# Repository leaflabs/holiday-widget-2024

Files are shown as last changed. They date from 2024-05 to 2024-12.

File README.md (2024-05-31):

# Holiday Widget

Basic startup project for NUCLEO-L053R8 board. 

Source code lives in firmware.

The build directory holds all .o files for compliation. The output binary is build/blink.elf. This folder is generated at compilation time and will not exist upon cloning the repository.

Include holds all user created .h files. For the HAL to work, the stm3l0xx_hal_conf_template.h file needs to be copied and adjusted as necessary. No changes were made as of now. 

src holds all user created .c files. This project does not use the c library so some builtin functions needed to be defined, namely __libc_init_array, memset and memcpy. main.c holds the main function and the basic code to blink the LD2 LED at a different speed when the B1 button is pressed.

linker_script.ld defines how the binary should be setup.  
  
Makefile has two main targets: build/blink.elf and upload  
build/blink.elf is also called by just calling 'make' and creates the .elf file. upload sends the .elf file to the Nucleo board.

The STM32CubeL0 and SmallPrintf folders are submodules for this repo. When cloning the project, run 'git submodule update --init --recursive' to create the folder.

Overall steps to get project and upload to nucleo board:
```
git clone --recursive <repo name> 
git submodule update --init --recursive
make
make upload
```

Dependencies:
* STM32CubeL0 at version v1.12.2
* eyalroz/printf at version v6.2.0-b1

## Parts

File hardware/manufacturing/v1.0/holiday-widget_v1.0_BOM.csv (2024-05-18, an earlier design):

Comment | Designator | Footprint | JLCPCB Part #（optional）
STM32L072RBTx | U1 | Package_QFP:LQFP-64_10x10mm_P0.5mm | C915968
TPS61200DRC | U2 | Package_SON:Texas_S-PVSON-N10_ThermalVias | C140320
LIS3DH | U3 | Package_LGA:LGA-16_3x3mm_P0.5mm_LayoutBorder3x5y | C15134
IMP23ABSU | U4 | Leaf_Microphone:RHLGA5_3P5X2P65X0P98_STM | C3171746
TMP102xxDRL | U5 | Package_TO_SOT_SMD:SOT-563 | C99269
VCNL_4020 | U6 | Leaf_Sensor:VCNL4020_SMD | C511034
PAM8302AAD | U7 | Package_SO:SSOP-8_2.95x2.8mm_P0.65mm | C113367
MMBT3906 | Q1,Q2,Q3,Q4,Q5,Q6,Q7,Q8 | Package_TO_SOT_SMD:SOT-23 | C2143
DNP | J1 |  | DNP
DNP | J2 |  | DNP
DNP | J3 |  | DNP
DNP | J4 |  | DNP
DNP | J5 |  | DNP
DNP | J6 |  | DNP
DNP | J7 |  | DNP
DNP | J33 |  | DNP
K2-1157SP-I4SW-01 | SW1,SW4 | Button_Switch_SMD:SW_Push_1P1T_NO_6x6mm_H9.5mm | C2909692
Test Points | TP1,TP2,TP3,TP4,TP5 | Leaf_Jumper:TestPoint_0.5mm_1mm | DNP
Green LED | D13, D19 | LED_SMD:LED_0805_2012Metric_Pad1.15x1.40mm_HandSolder | C965816
Yellow LED | D14, D15, D16, D20, D21, D22, D6, D8, D10, D26, D27, D28 | LED_SMD:LED_0805_2012Metric_Pad1.15x1.40mm_HandSolder | C2296
Green LED | D12, D17, D18, D9, D7, D5, D23, D24, D25, D11 | LED_SMD:LED_0805_2012Metric_Pad1.15x1.40mm_HandSolder | C965816
Red LED | D1, D2, D3, D4 | LED_SMD:LED_0805_2012Metric_Pad1.15x1.40mm_HandSolder | C84256
50 | R15, R16, R17, R18, R19, R20, R21, R22 | Resistor_SMD:R_0603_1608Metric_Pad0.98x0.95mm_HandSolder
120 | R11,R12,R13,R14 | Resistor_SMD:R_0603_1608Metric_Pad0.98x0.95mm_HandSolder
10k | R1,R2,R3,R6,R7,R8 | Resistor_SMD:R_0603_1608Metric_Pad0.98x0.95mm_HandSolder
1M | R4 | Resistor_SMD:R_0603_1608Metric_Pad0.98x0.95mm_HandSolder
180k | R5 | Resistor_SMD:R_0603_1608Metric_Pad0.98x0.95mm_HandSolder
0 | R9,R23,R24 | Resistor_SMD:R_0603_1608Metric_Pad0.98x0.95mm_HandSolder
100k | R10,R25,R26 | Resistor_SMD:R_0603_1608Metric_Pad0.98x0.95mm_HandSolder
4.7u | C1 | Capacitor_SMD:C_0603_1608Metric_Pad1.08x0.95mm_HandSolder | C1953079
10u | C11,C15,C19,C23 | Capacitor_SMD:C_0603_1608Metric_Pad1.08x0.95mm_HandSolder | C2959727
4.7u | C9 | Capacitor_SMD:C_0603_1608Metric_Pad1.08x0.95mm_HandSolder | C108342
100n | C2,C3,C4,C5,C7,C8,C10,C14,C17,C20, C21 | Capacitor_SMD:C_0603_1608Metric_Pad1.08x0.95mm_HandSolder | C66501
1u | C6,C13 | Capacitor_SMD:C_0603_1608Metric_Pad1.08x0.95mm_HandSolder | C59302
1n | C12 | Capacitor_SMD:C_0603_1608Metric_Pad1.08x0.95mm_HandSolder | C44369
22u | C16 | Capacitor_SMD:C_0603_1608Metric_Pad1.08x0.95mm_HandSolder | C43922
10n | C18 | Capacitor_SMD:C_0603_1608Metric_Pad1.08x0.95mm_HandSolder | C30926
LPS3015-222MRC | L1 | Inductor_SMD:L_Coilcraft_LPS3010 | C2844756

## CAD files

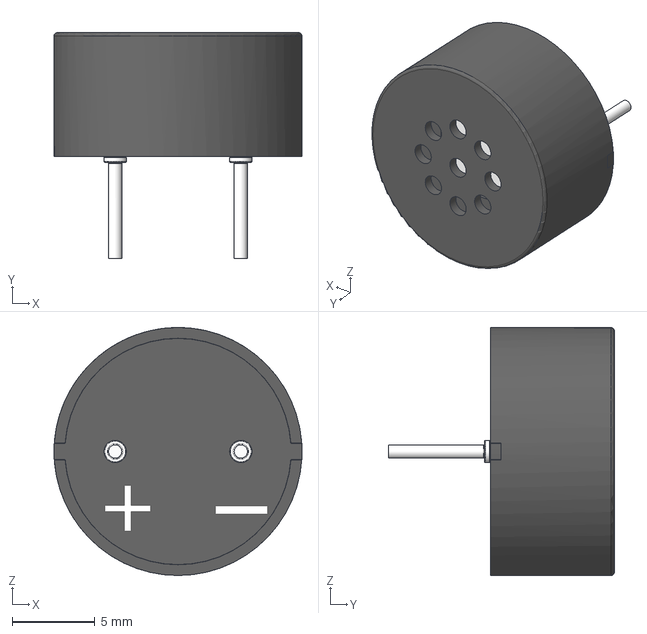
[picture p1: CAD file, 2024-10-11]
hardware/holiday-widget-models/AST-01508MR-WT-R--3DModel-STEP-461651.STEP
15.0 x 13.7 x 15.0 mm

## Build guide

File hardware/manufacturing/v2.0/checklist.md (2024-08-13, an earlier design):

# General
- [ ] Design rules set appropriately for fab house?
  - Which Fab is being used? : JLC
  - How many PCB layers?:
    - [ ] 2
    - [X] 4
    - [ ] 6
    - [ ] 8
  - Special PCB Requirements?:
    - [ ] Blind Buried Vias
    - [ ] Capped Vias
    - [ ] Rigid/Flex
- [X] ERC passes?
  - [X] ERC report included?
- [X] DRC passes?
  - [X] DRC report included?
- [X] Appropriate copper weight selected?

# BOM
- [X] Components in stock?
- [X] Specialty components recommended for new designs?
- [X] All specialty components added to design library?
- [X] Resistors / Capacitors rated appropriately?

# Schematic
## General
- [ ] Net classes assigned for critical nets?
- [X] Test points added to critical nets?
- [X] Gound points near test points?
- [X] Proper and judicious use of heirarchical schematics? 
- [X] Diodes properly oriented?
- [X] Schematic included in manufacturing folder?

## Digital
- [X] Decoupling caps on all digital chips?
- [ ] Inputs appropriately protected?
- [X] Bus signals appropriately terminated?
	- [X] I2C Terminated?
	- [ ] SPI tied off?
- [X] Ferrite beads placed on high speed / high noise ICs?
	- PLLs
	- Oscillators
	- Chips with very high speeds

## MCU
- [X] JTAG broken out?
- [X] LED/Debug IO broken out?
- [X] Able to initiate bootloader?
  - i.e. are boot/reset lines broken out to jumper/button?
- [X] GPIOs don't interfere with boot/reset pins

## Power Electronics
- [ ] Proper capacitance on both sides of load switches?
- [X] Power supplies rated appropriately?
- [X] Power supplies have sufficient bulk capacitance?
- [X] All components connected to correct power net?
- [ ] Voltage drop accounted for over cables?

# Layout
- [X] Silkscreen Complete?
	- [X] Version?
	- [X] Name?
	- [X] Connectors labeled?
    - [X] Designators placed/spaced and sized properly for all components?
	- [X] Silkscreen doesn't overlap with drill hits or other features that'd make it illegible?
- [X] Design properly floorplanned?
	- [ ] Analog / Digital / Power separated?
- [ ] Differential signals skew matched?
- [ ] Clocked data lines skew matched?
- [X] Routing only on appropriate layers?
- [ ] Appropriate separation for high voltage?
- [X] Elements with >1 row of pin headers have their own footprint?
- [X] (If ordering via gerber upload) Gerber files included in manufacturing folder?

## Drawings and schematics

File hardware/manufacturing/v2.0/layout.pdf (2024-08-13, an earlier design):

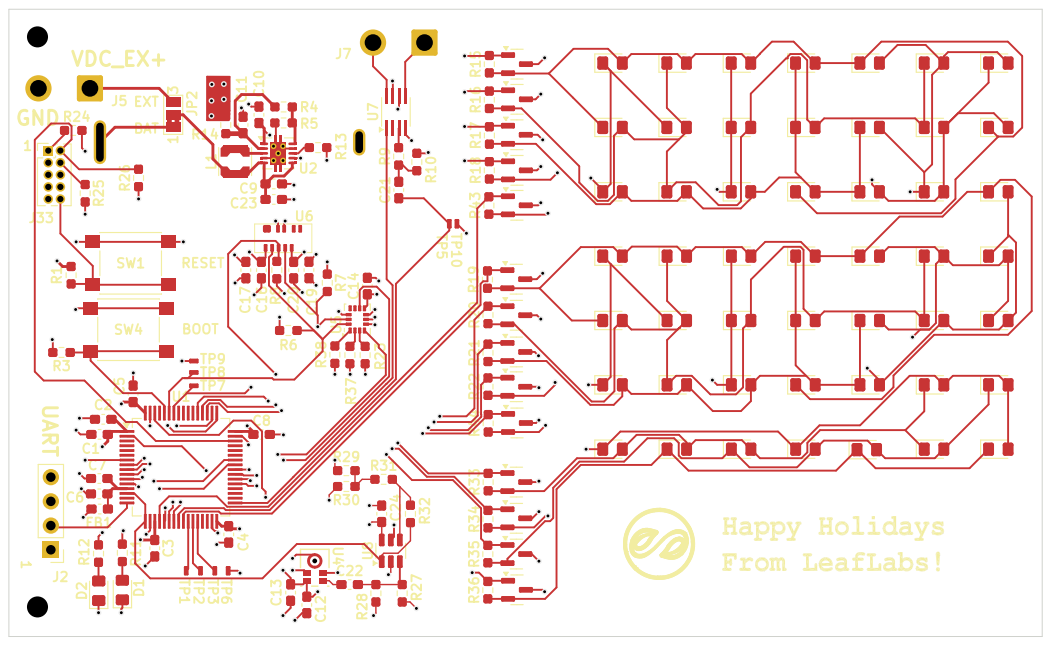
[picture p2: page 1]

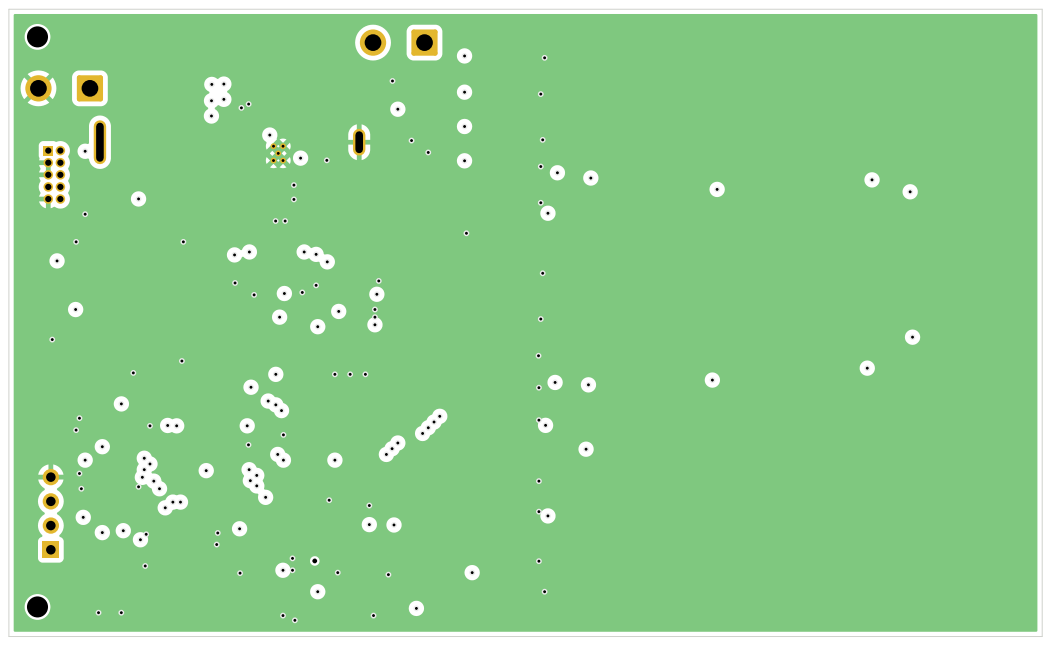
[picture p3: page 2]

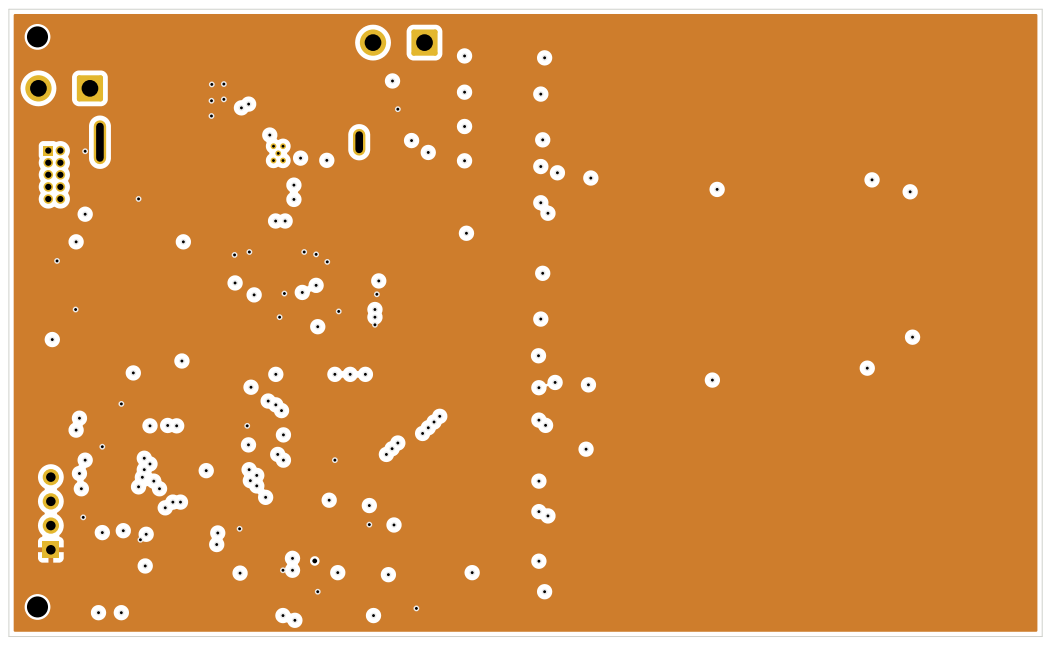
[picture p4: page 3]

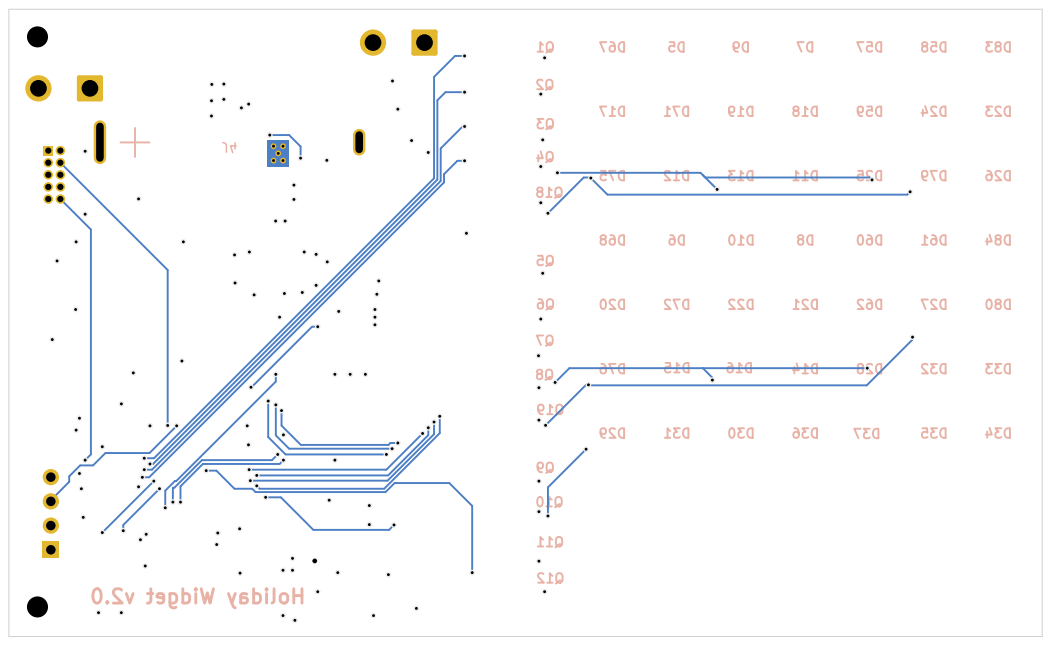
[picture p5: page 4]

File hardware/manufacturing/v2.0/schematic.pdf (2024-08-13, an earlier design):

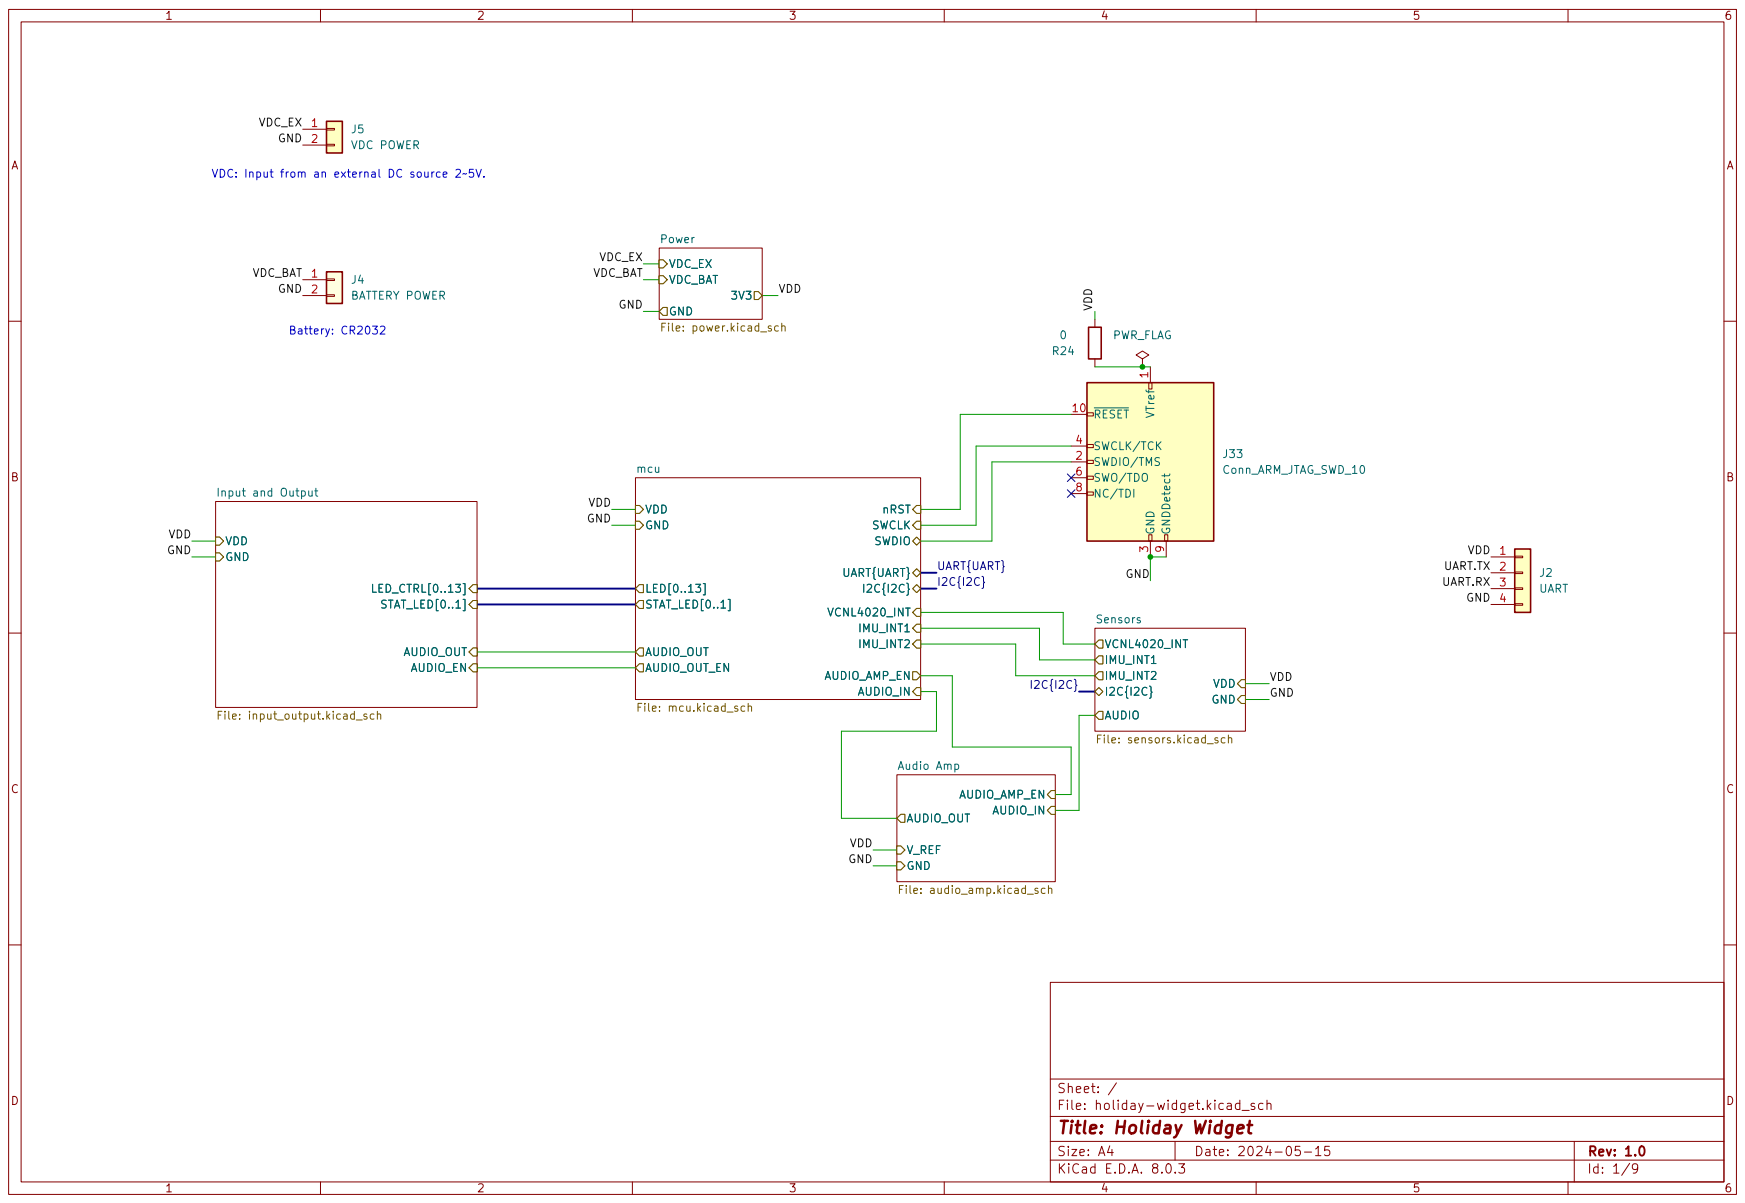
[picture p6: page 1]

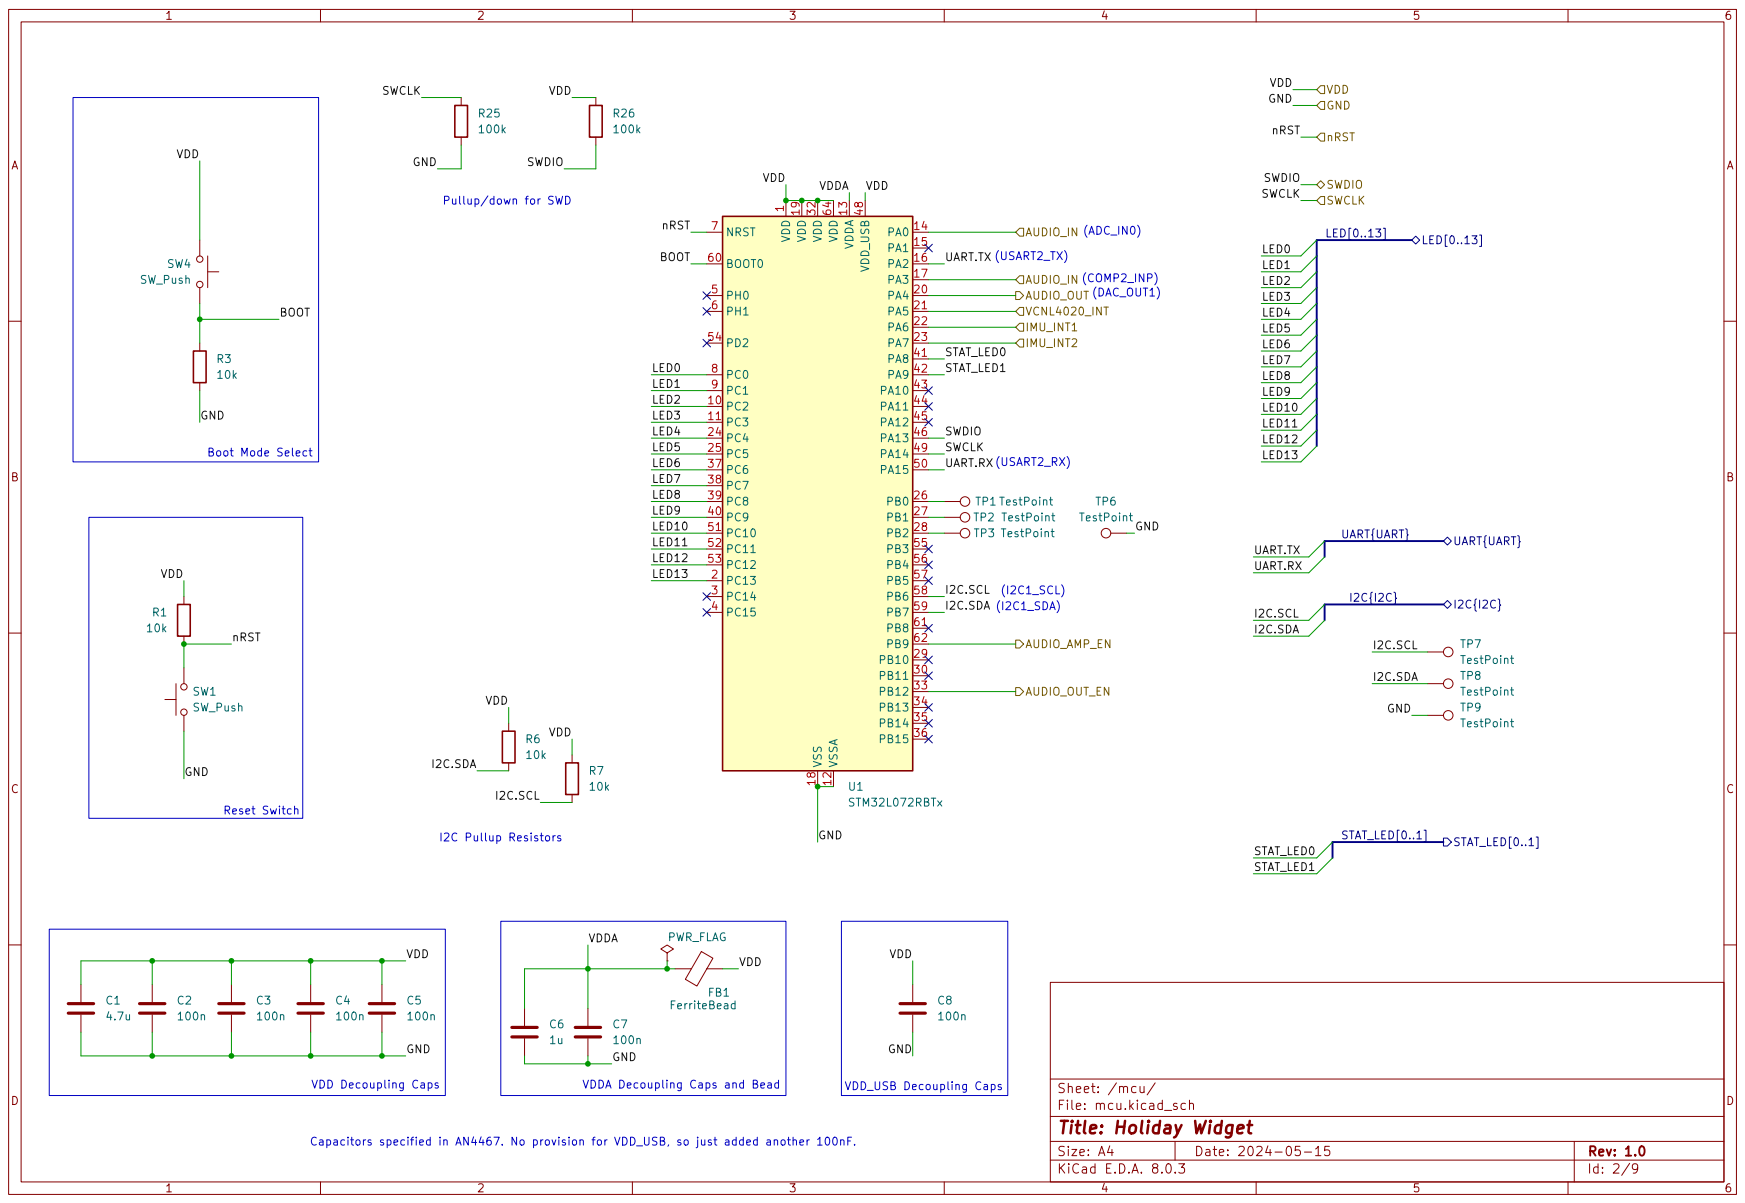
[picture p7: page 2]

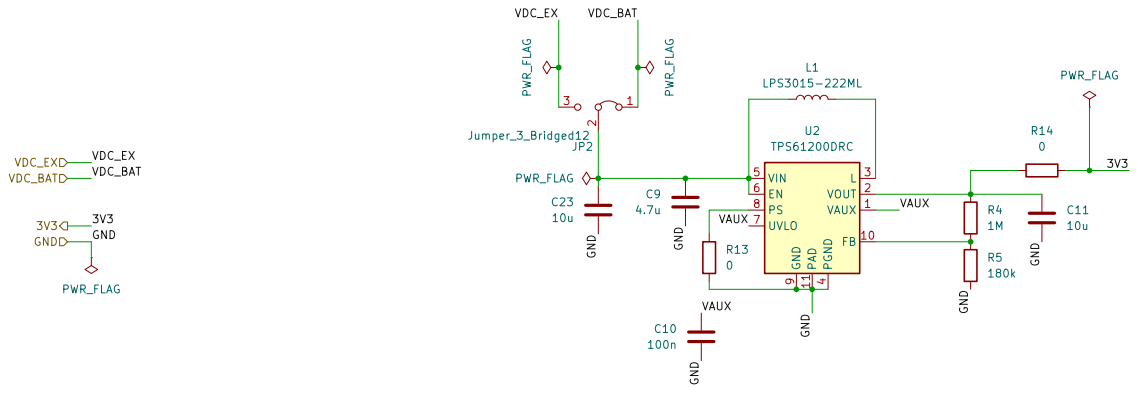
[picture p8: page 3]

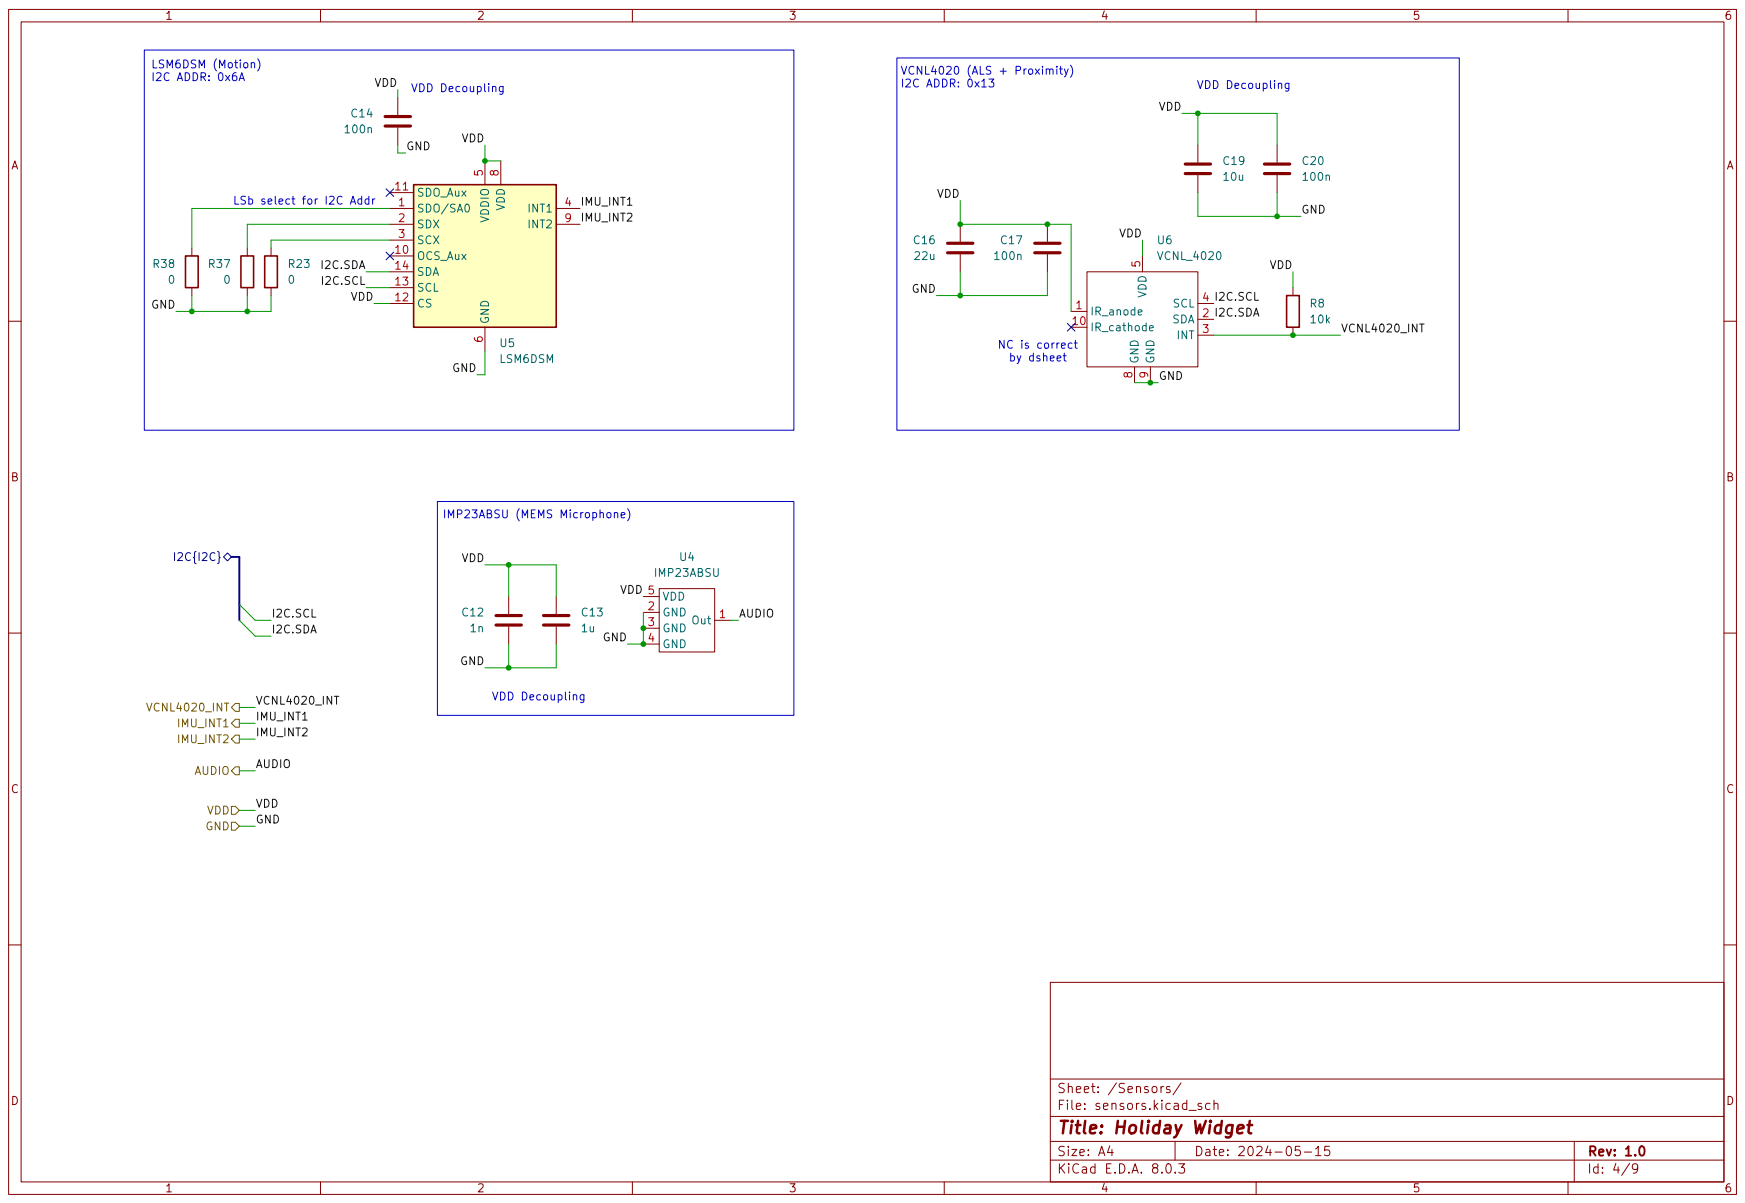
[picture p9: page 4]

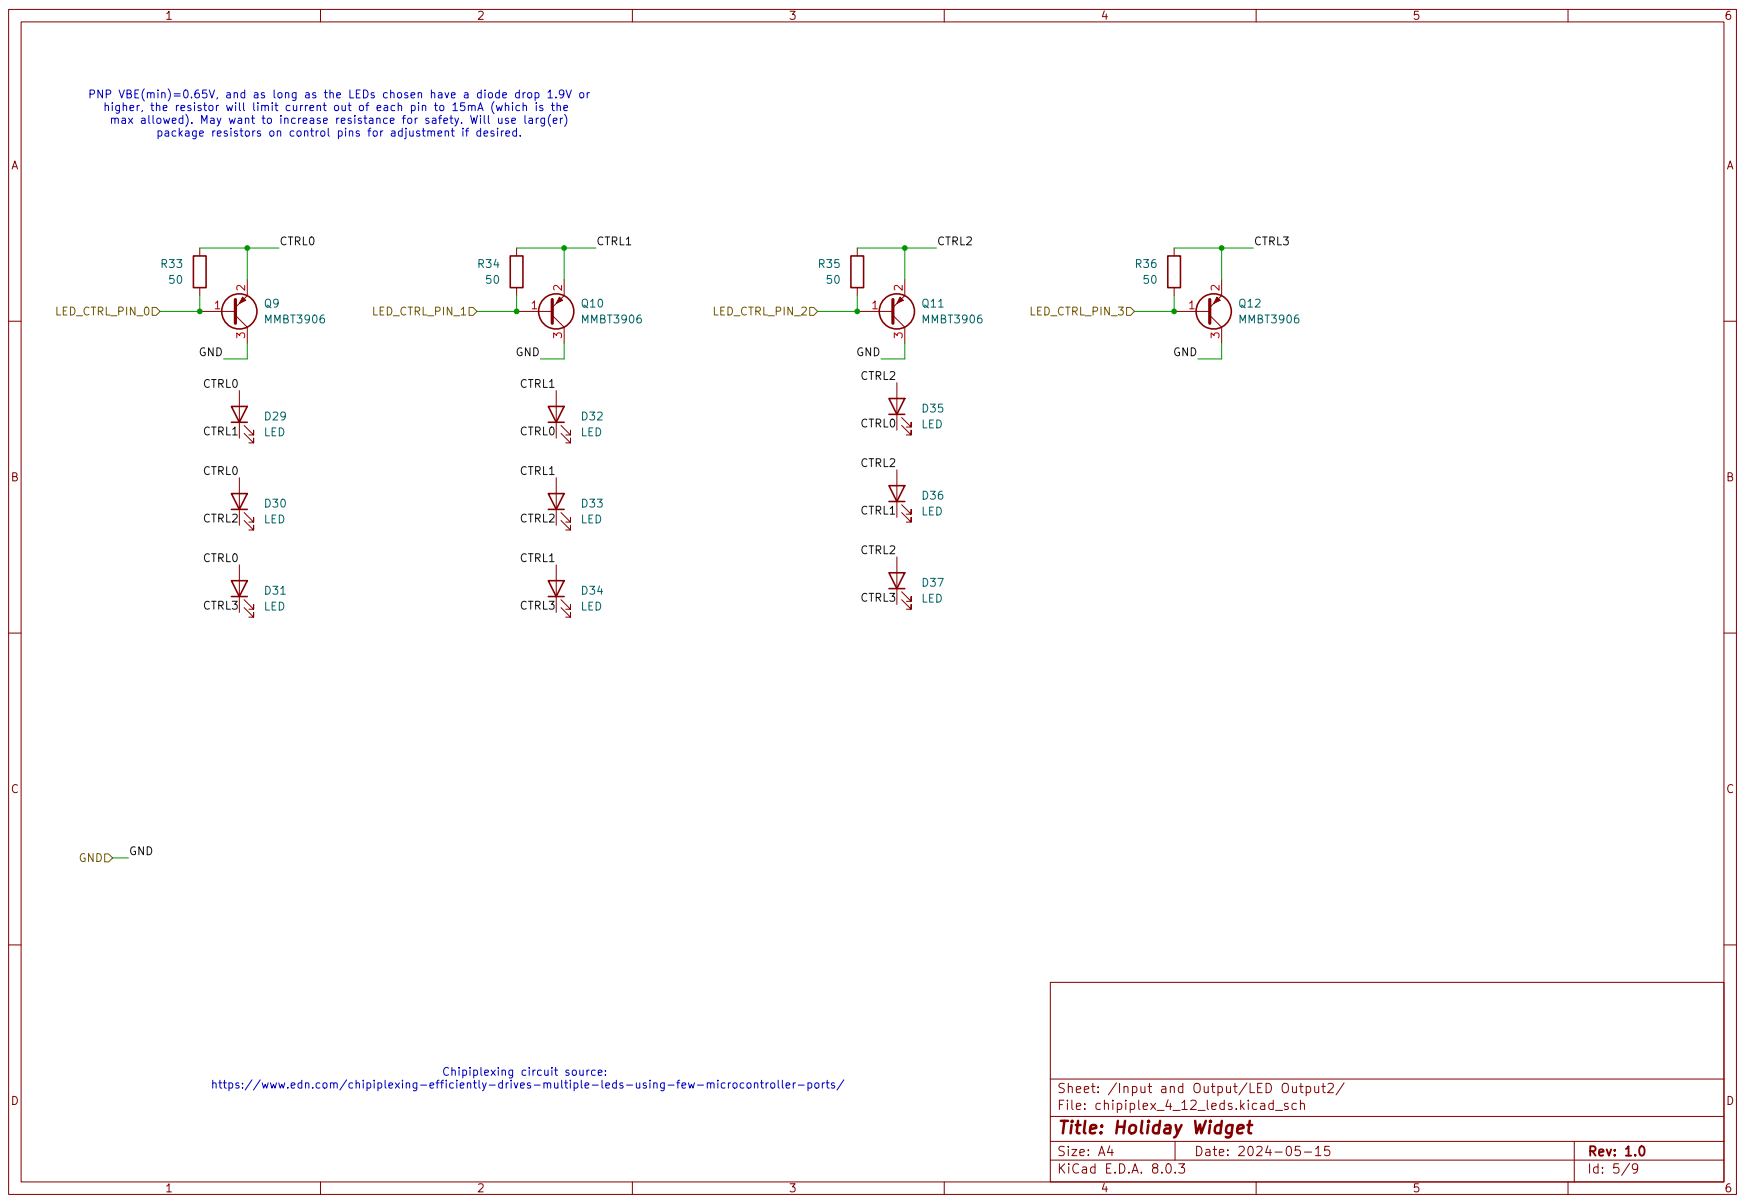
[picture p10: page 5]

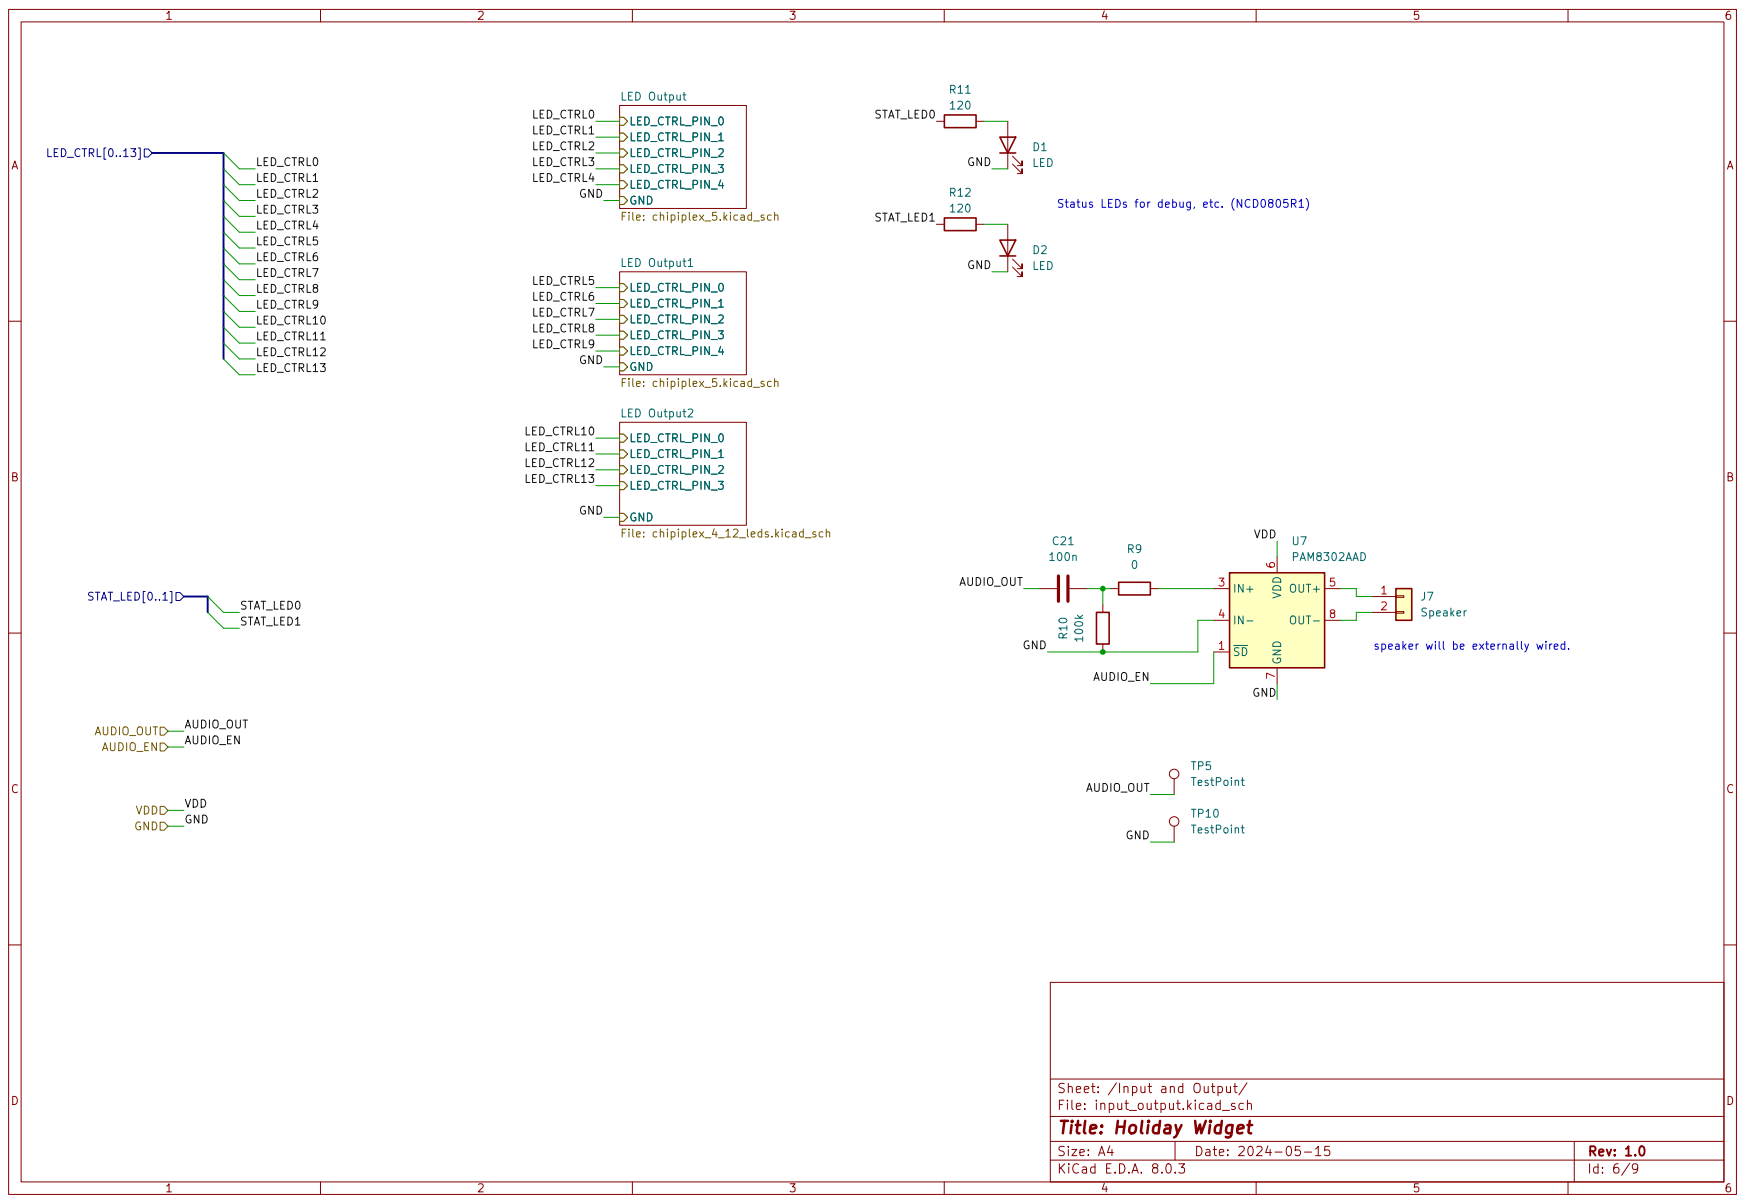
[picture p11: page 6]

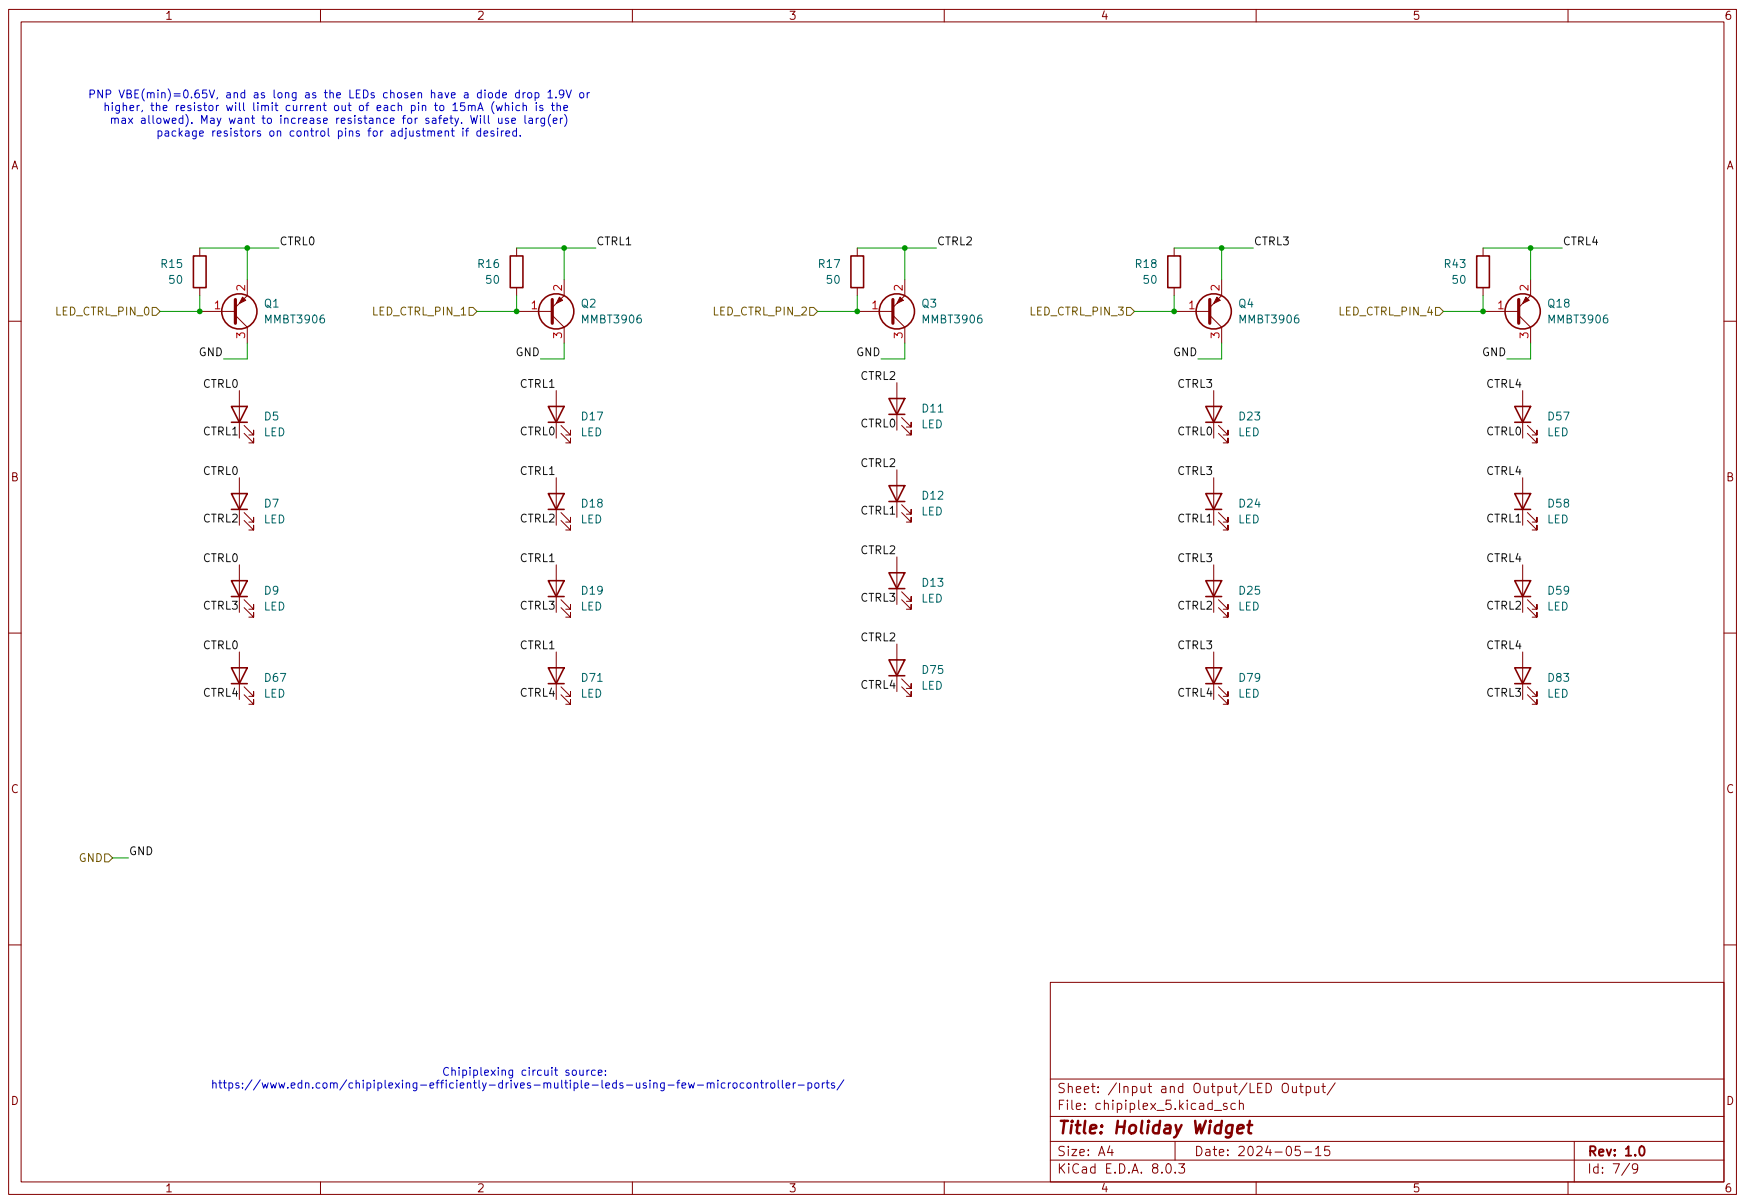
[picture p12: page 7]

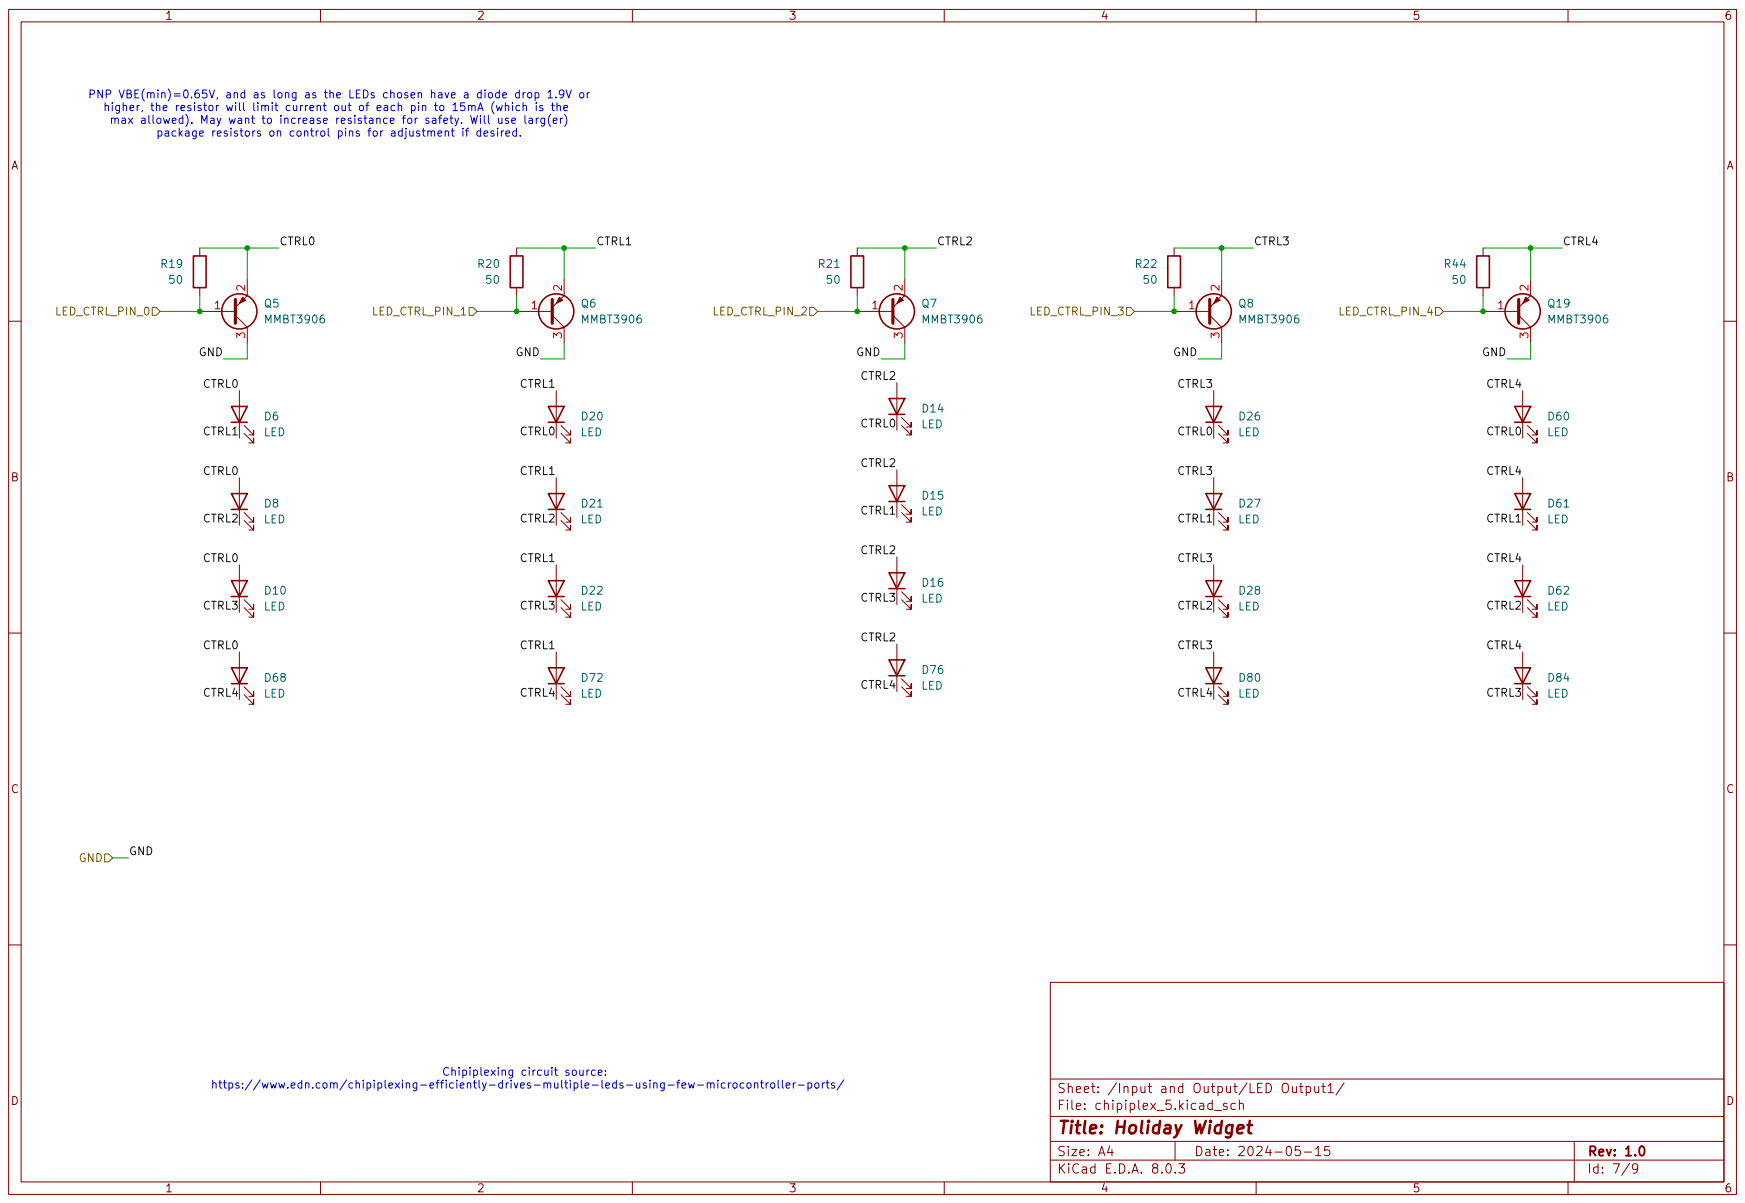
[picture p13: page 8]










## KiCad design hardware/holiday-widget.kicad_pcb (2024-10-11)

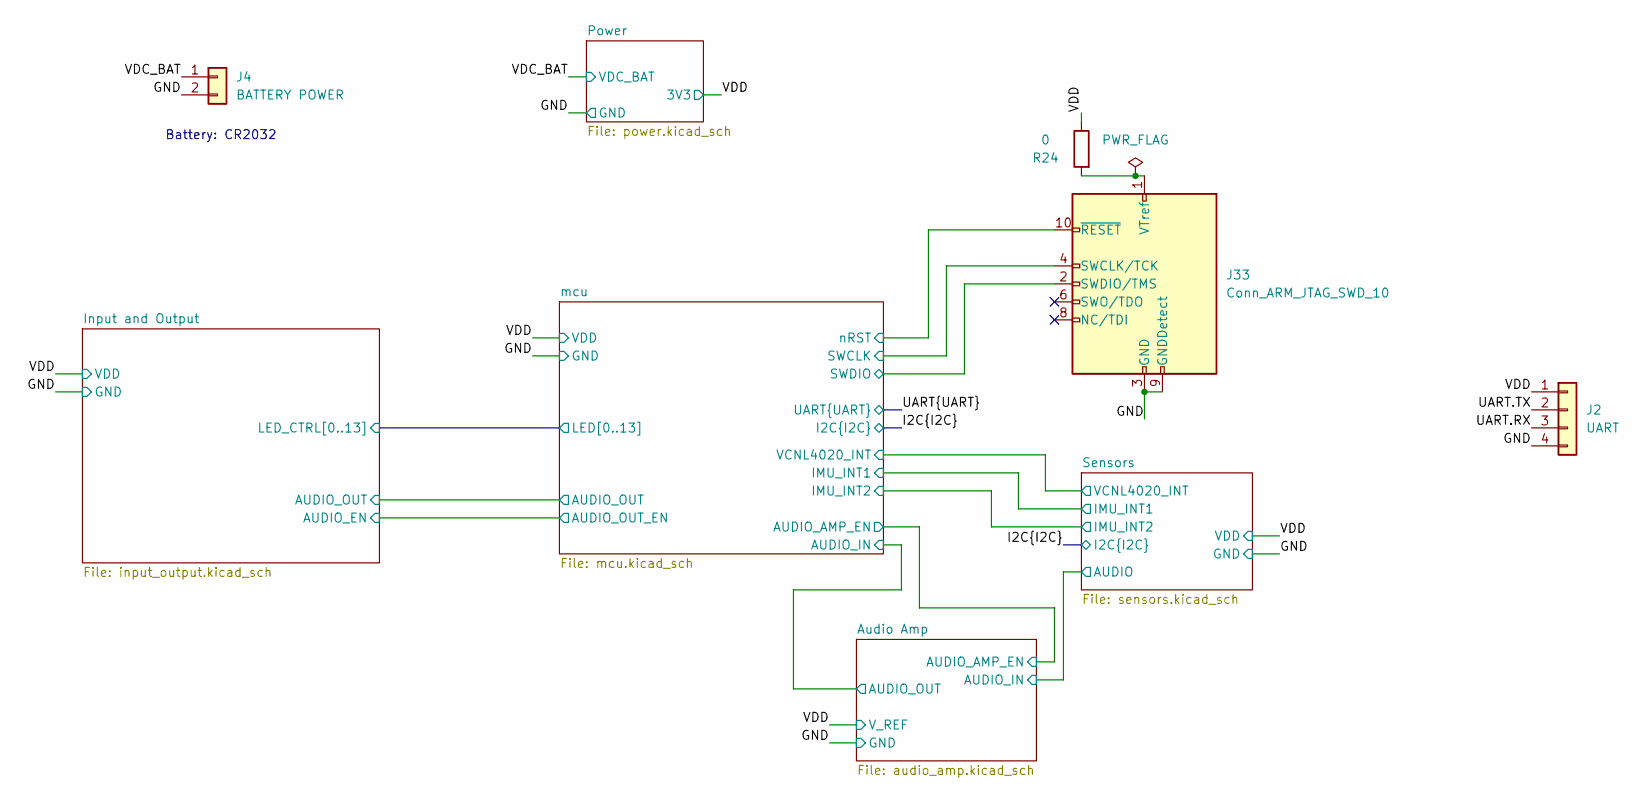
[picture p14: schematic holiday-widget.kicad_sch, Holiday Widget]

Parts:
J2: UART; PinHeader_1x04_P2.00mm_Vertical
J4: BATTERY POWER; MPD_BC2032-E2
J33: Conn_ARM_JTAG_SWD_10; PinHeader_2x05_P1.27mm_Vertical
R24: 0; R_0402_1005Metric; MPN RC0402JR-070RL

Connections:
/GND: J2.4, J4.2, J33.3 (GND), J33.5 (GND), J33.9 (GNDDetect); also elsewhere on the board
/UART.RX: J2.3; also elsewhere on the board
/UART.TX: J2.2; also elsewhere on the board
/VDC_BAT: J4.1; also elsewhere on the board
/VDD: J2.1, R24.1; also elsewhere on the board
/mcu/SWCLK: J33.4 (SWCLK/TCK); also elsewhere on the board
/mcu/SWDIO: J33.2 (SWDIO/TMS); also elsewhere on the board
/mcu/nRST: J33.10 (~RESET); also elsewhere on the board
unnamed: J33.1 (VTref), R24.2

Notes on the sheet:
Battery: CR2032

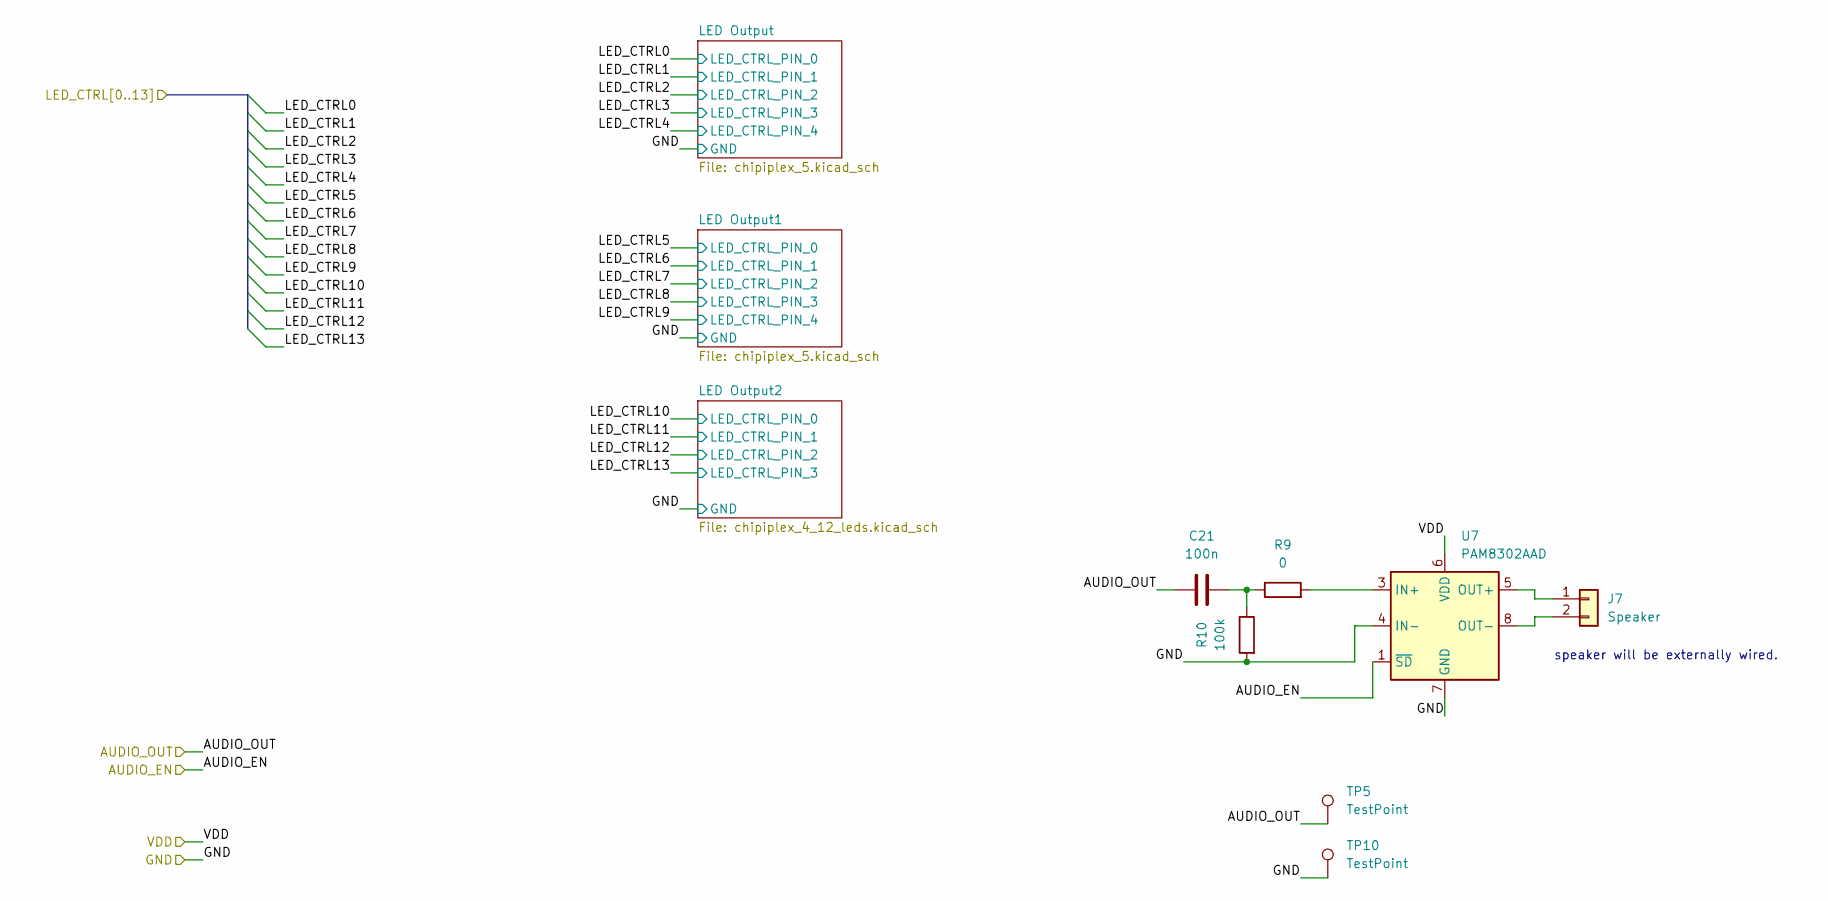
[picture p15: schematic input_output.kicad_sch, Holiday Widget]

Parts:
C21: 100n; C_0402_1005Metric; MPN CL05A104KA5NNNC
J7: Speaker; SPKR_AST-01508MR-WT-R
R9: 0; R_0402_1005Metric; MPN RC0402JR-070RL
R10: 100k; R_0402_1005Metric; MPN RC0402FR-07100KL
TP5, TP10: TestPoint; TestPoint_0.5mm_1mm
U7: PAM8302AAD; SSOP-8_2.95x2.8mm_P0.65mm; MPN PAM8302AADCR

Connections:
/GND: R10.2, TP10.1, U7.4 (IN-), U7.7 (GND); also elsewhere on the board
/Input and Output/AUDIO_EN: U7.1 (~SD); also elsewhere on the board
/Input and Output/AUDIO_OUT: C21.1, TP5.1; also elsewhere on the board
/VDD: U7.6 (VDD); also elsewhere on the board
unnamed: C21.2, R9.1, R10.1
unnamed: J7.1, U7.5 (OUT+)
unnamed: J7.2, U7.8 (OUT-)
unnamed: R9.2, U7.3 (IN+)

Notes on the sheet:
speaker will be externally wired.

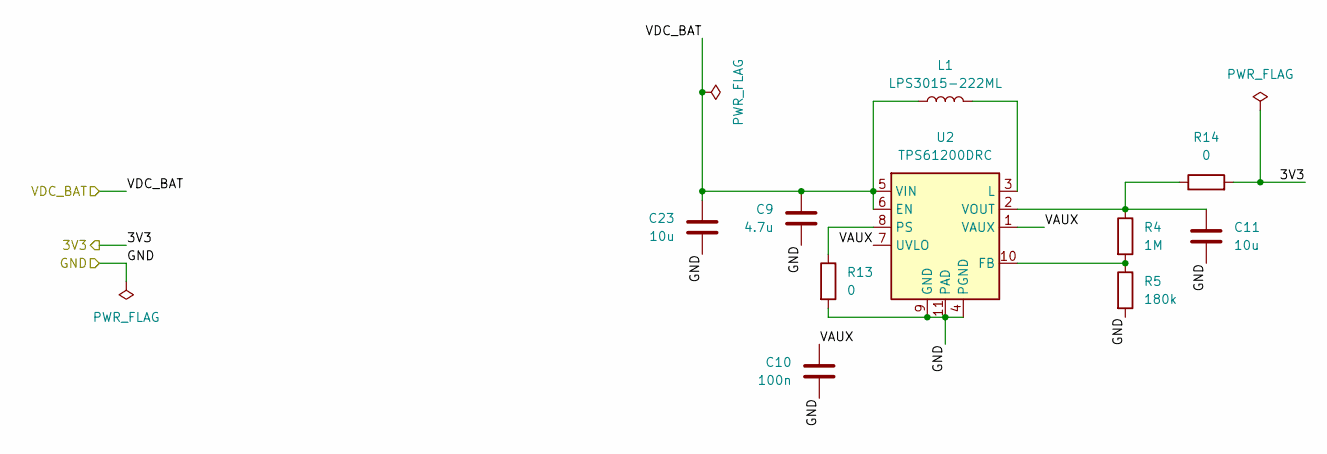
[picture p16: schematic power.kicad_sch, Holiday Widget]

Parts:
C9: 4.7u; C_0402_1005Metric; MPN CL05A475MP5NRNC
C10: 100n; C_0402_1005Metric; MPN CL05A104KA5NNNC
C11, C23: 10u; C_0603_1608Metric_Pad1.08x0.95mm_HandSolder; MPN CL10A106MQ8NNNC
L1: LPS3015-222ML; L_Coilcraft_LPS3010; MPN LPS3015-222MRC
R4: 1M; R_0402_1005Metric; MPN RC0402FR-071ML
R5: 180k; R_0402_1005Metric; MPN RC0402JR-07180KL
R13, R14: 0; R_0402_1005Metric; MPN RC0402JR-070RL
U2: TPS61200DRC; Texas_S-PVSON-N10_ThermalVias; MPN TPS61200DRCT

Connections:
/GND: C9.2, C10.2, C11.2, C23.2, R5.2, R13.2, U2.4 (PGND), U2.9 (GND), U2.11 (PAD); also elsewhere on the board
/Power/VAUX: C10.1, U2.1 (VAUX), U2.7 (UVLO)
/VDC_BAT: C9.1, C23.1, L1.1, U2.5 (VIN), U2.6 (EN); also elsewhere on the board
/VDD: R14.2; also elsewhere on the board
unnamed: R4.2, R5.1, U2.10 (FB)
unnamed: L1.2, U2.3 (L)
unnamed: R13.1, U2.8 (PS)
unnamed: C11.1, R4.1, R14.1, U2.2 (VOUT)

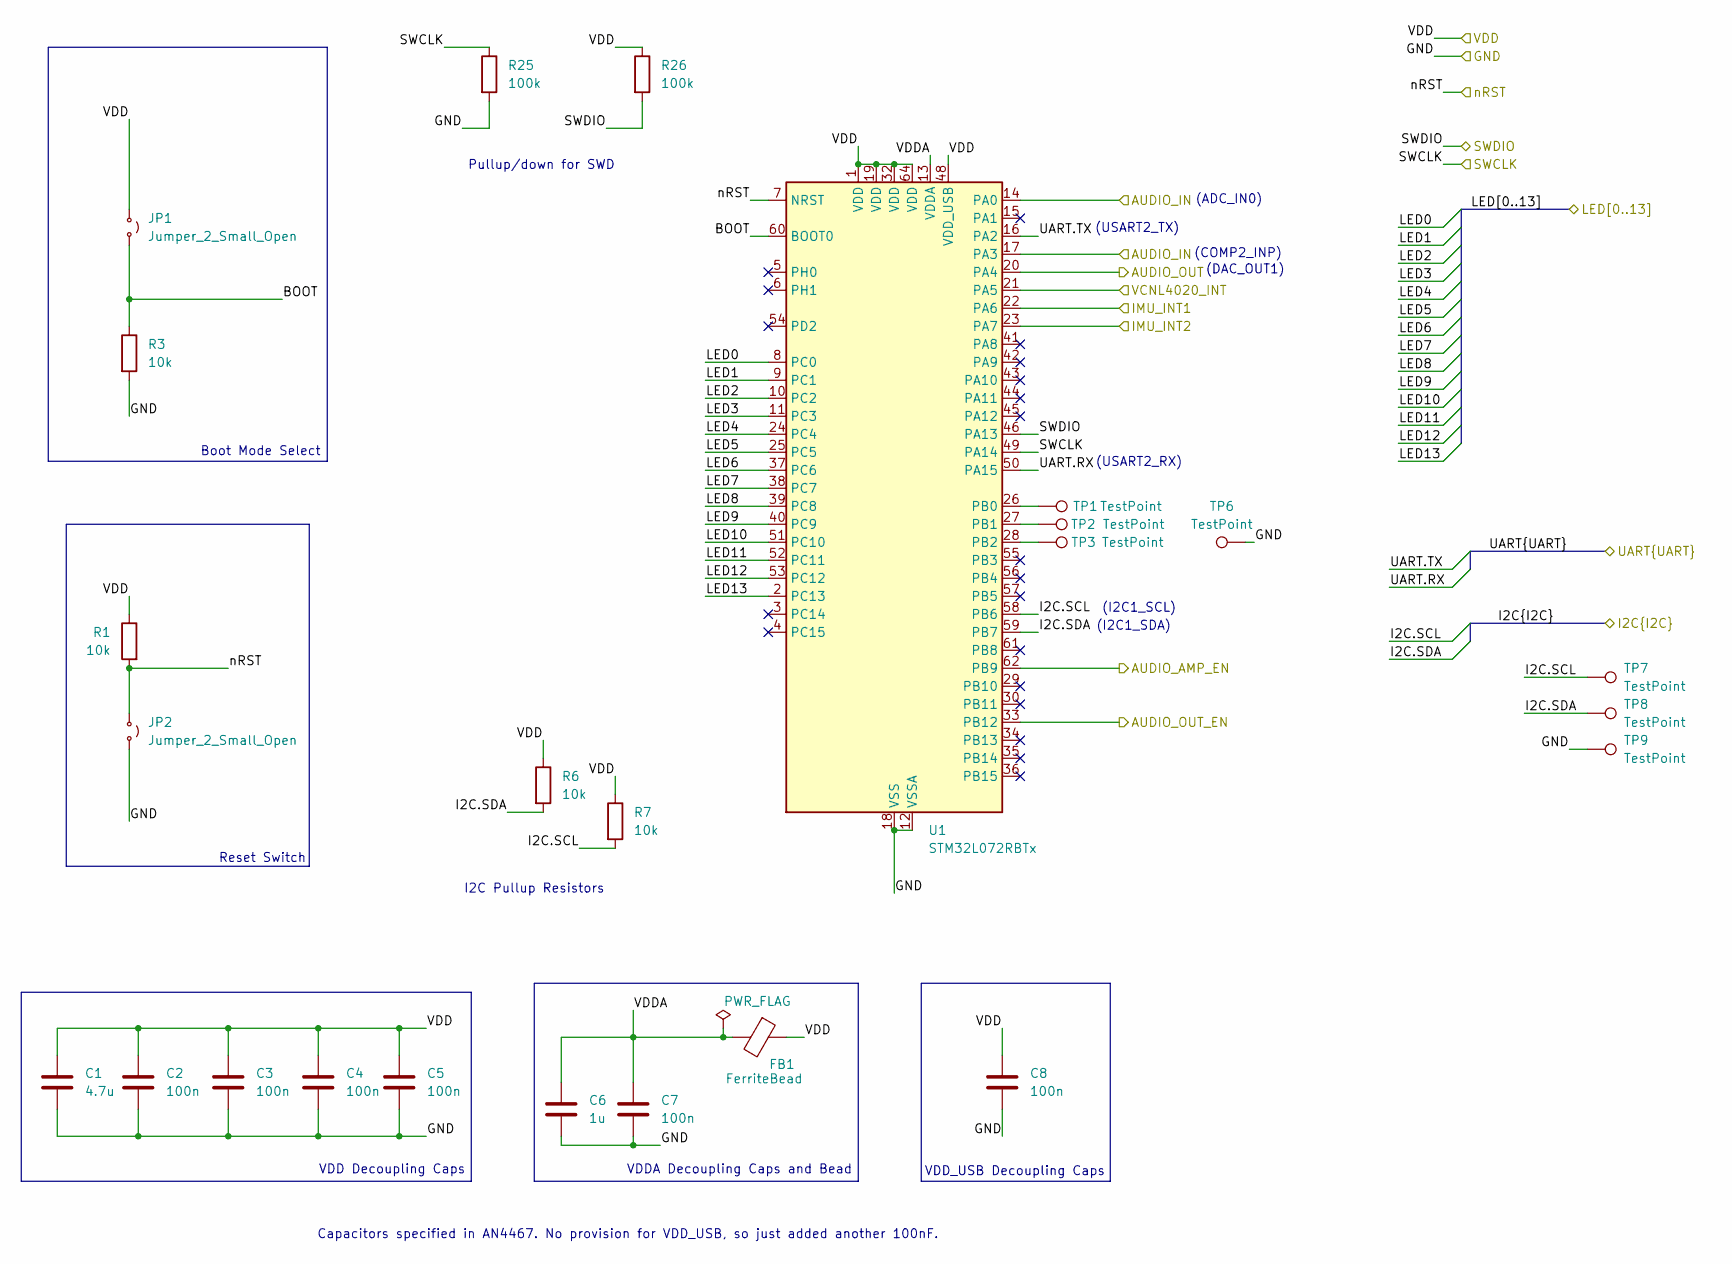
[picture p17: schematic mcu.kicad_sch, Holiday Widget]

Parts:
C1: 4.7u; C_0402_1005Metric; MPN CL05A475MP5NRNC
C2, C3, C4, C5, C7, C8: 100n; C_0402_1005Metric; MPN CL05A104KA5NNNC
C6: 1u; C_0603_1608Metric_Pad1.08x0.95mm_HandSolder; MPN CL05A105KO5NNNC
FB1: FerriteBead; C_0603_1608Metric_Pad1.08x0.95mm_HandSolder; MPN 742792662
JP1, JP2: Jumper_2_Small_Open; SolderJumper-2_P1.3mm_Open_RoundedPad1.0x1.5mm
R1, R3, R6, R7: 10k; R_0402_1005Metric; MPN RC0402FR-0710KL
R25, R26: 100k; R_0402_1005Metric; MPN RC0402FR-07100KL
TP1, TP2, TP3, TP6, TP7, TP8, TP9: TestPoint; TestPoint_0.5mm_1mm
U1: STM32L072RBTx; LQFP-64_10x10mm_P0.5mm; MPN STM32L072RBT6

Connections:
/Audio Amp/AUDIO_AMP_EN: U1.62 (PB9); also elsewhere on the board
/Audio Amp/AUDIO_OUT: U1.14 (PA0), U1.17 (PA3); also elsewhere on the board
/GND: C1.2, C2.2, C3.2, C4.2, C5.2, C6.2, C7.2, C8.2, JP2.2 (B), R3.2, R25.2, TP6.1, TP9.1, U1.12 (VSSA), U1.18 (VSS), U1.31 (VSS), U1.47 (VSS), U1.63 (VSS); also elsewhere on the board
/I2C.SCL: R7.2, TP7.1, U1.58 (PB6); also elsewhere on the board
/I2C.SDA: R6.2, TP8.1, U1.59 (PB7); also elsewhere on the board
/Input and Output/AUDIO_EN: U1.33 (PB12); also elsewhere on the board
/Input and Output/AUDIO_OUT: U1.20 (PA4); also elsewhere on the board
/Sensors/IMU_INT1: U1.22 (PA6); also elsewhere on the board
/Sensors/IMU_INT2: U1.23 (PA7); also elsewhere on the board
/Sensors/VCNL4020_INT: U1.21 (PA5); also elsewhere on the board
/UART.RX: U1.50 (PA15); also elsewhere on the board
/UART.TX: U1.16 (PA2); also elsewhere on the board
/VDD: C1.1, C2.1, C3.1, C4.1, C5.1, C8.1, FB1.1, JP1.1 (A), R1.1, R6.1, R7.1, R26.1, U1.1 (VDD), U1.19 (VDD), U1.32 (VDD), U1.48 (VDD_USB), U1.64 (VDD); also elsewhere on the board
/mcu/BOOT: JP1.2 (B), R3.1, U1.60 (BOOT0)
/mcu/LED0: U1.8 (PC0); also elsewhere on the board
/mcu/LED1: U1.9 (PC1); also elsewhere on the board
/mcu/LED2: U1.10 (PC2); also elsewhere on the board
/mcu/LED3: U1.11 (PC3); also elsewhere on the board
/mcu/LED4: U1.24 (PC4); also elsewhere on the board
/mcu/LED5: U1.25 (PC5); also elsewhere on the board
/mcu/LED6: U1.37 (PC6); also elsewhere on the board
/mcu/LED7: U1.38 (PC7); also elsewhere on the board
/mcu/LED8: U1.39 (PC8); also elsewhere on the board
/mcu/LED9: U1.40 (PC9); also elsewhere on the board
/mcu/LED10: U1.51 (PC10); also elsewhere on the board
/mcu/LED11: U1.52 (PC11); also elsewhere on the board
/mcu/LED12: U1.53 (PC12); also elsewhere on the board
/mcu/LED13: U1.2 (PC13); also elsewhere on the board
/mcu/SWCLK: R25.1, U1.49 (PA14); also elsewhere on the board
/mcu/SWDIO: R26.2, U1.46 (PA13); also elsewhere on the board
/mcu/VDDA: C6.1, C7.1, FB1.2, U1.13 (VDDA)
/mcu/nRST: JP2.1 (A), R1.2, U1.7 (NRST); also elsewhere on the board
unnamed: TP1.1, U1.26 (PB0)
unnamed: TP2.1, U1.27 (PB1)
unnamed: TP3.1, U1.28 (PB2)

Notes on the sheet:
Capacitors specified in AN4467. No provision for VDD_USB, so just added another 100nF.
Reset Switch
I2C Pullup Resistors
(COMP2_INP)
VDD_USB Decoupling Caps
VDDA Decoupling Caps and Bead
(ADC_IN0)
(USART2_TX)
Boot Mode Select
Pullup/down for SWD
VDD Decoupling Caps
(I2C1_SCL)
(USART2_RX)
(DAC_OUT1)
(I2C1_SDA)

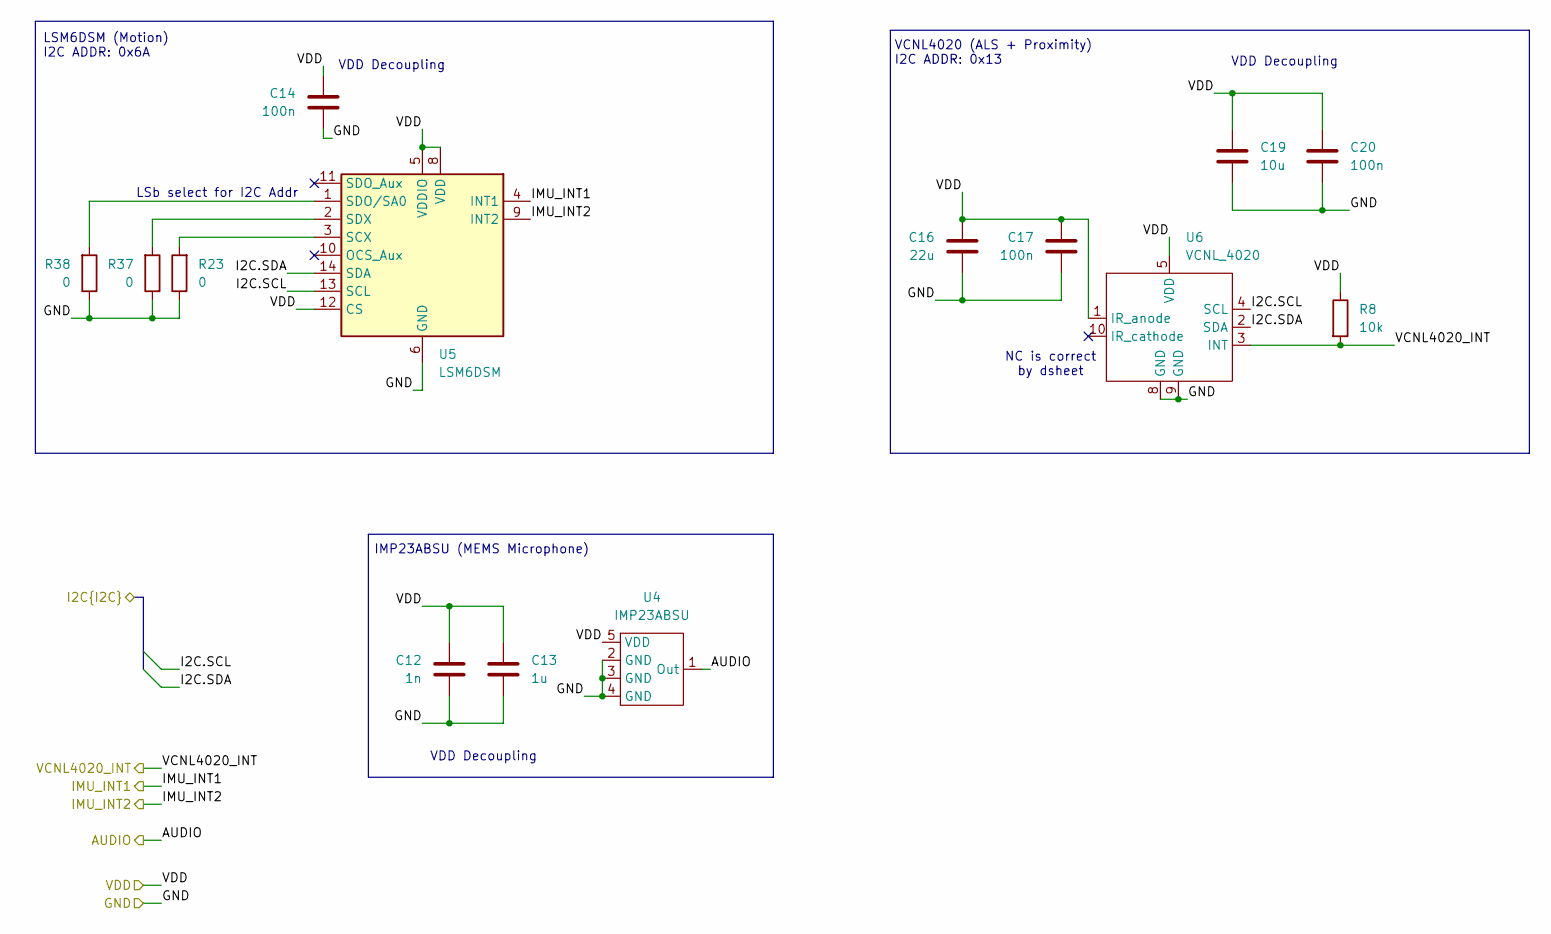
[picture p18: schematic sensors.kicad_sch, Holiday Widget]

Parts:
C12: 1n; C_0402_1005Metric; MPN C0402C102K4RACTU
C13: 1u; C_0603_1608Metric_Pad1.08x0.95mm_HandSolder; MPN CL05A105KO5NNNC
C14, C17, C20: 100n; C_0402_1005Metric; MPN CL05A104KA5NNNC
C16: 22u; C_0603_1608Metric_Pad1.08x0.95mm_HandSolder; MPN CL10A226MO7JZNC
C19: 10u; C_0603_1608Metric_Pad1.08x0.95mm_HandSolder; MPN CL10A106MQ8NNNC
R8: 10k; R_0402_1005Metric; MPN RC0402FR-0710KL
R23, R37, R38: 0; R_0402_1005Metric; MPN RC0402JR-070RL
U4: IMP23ABSU; RHLGA5_3P5X2P65X0P98_STM; MPN IMP23ABSUTR
U5: LSM6DSM; LGA-14_3x2.5mm_P0.5mm_LayoutBorder3x4y; MPN LSM6DSMTR
U6: VCNL_4020; VCNL4020_SMD; MPN VCNL4020-GS08

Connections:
/Audio Amp/AUDIO_IN: U4.1 (Out); also elsewhere on the board
/GND: C12.2, C13.2, C14.2, C16.2, C17.2, C19.2, C20.2, R23.1, R37.1, R38.1, U4.2 (GND), U4.3 (GND), U4.4 (GND), U5.6 (GND), U5.7 (GND), U6.8 (GND), U6.9 (GND); also elsewhere on the board
/I2C.SCL: U5.13 (SCL), U6.4 (SCL); also elsewhere on the board
/I2C.SDA: U5.14 (SDA), U6.2 (SDA); also elsewhere on the board
/Sensors/IMU_INT1: U5.4 (INT1); also elsewhere on the board
/Sensors/IMU_INT2: U5.9 (INT2); also elsewhere on the board
/Sensors/VCNL4020_INT: R8.2, U6.3 (INT); also elsewhere on the board
/VDD: C12.1, C13.1, C14.1, C16.1, C17.1, C19.1, C20.1, R8.1, U4.5 (VDD), U5.5 (VDDIO), U5.8 (VDD), U5.12 (CS), U6.1 (IR_anode), U6.5 (VDD); also elsewhere on the board
unnamed: R23.2, U5.3 (SCX)
unnamed: R38.2, U5.1 (SDO/SA0)
unnamed: R37.2, U5.2 (SDX)

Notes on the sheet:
IMP23ABSU (MEMS Microphone)
LSb select for I2C Addr
VDD Decoupling
NC is correct by dsheet
LSM6DSM (Motion) I2C ADDR: 0x6A
VCNL4020 (ALS + Proximity) I2C ADDR: 0x13

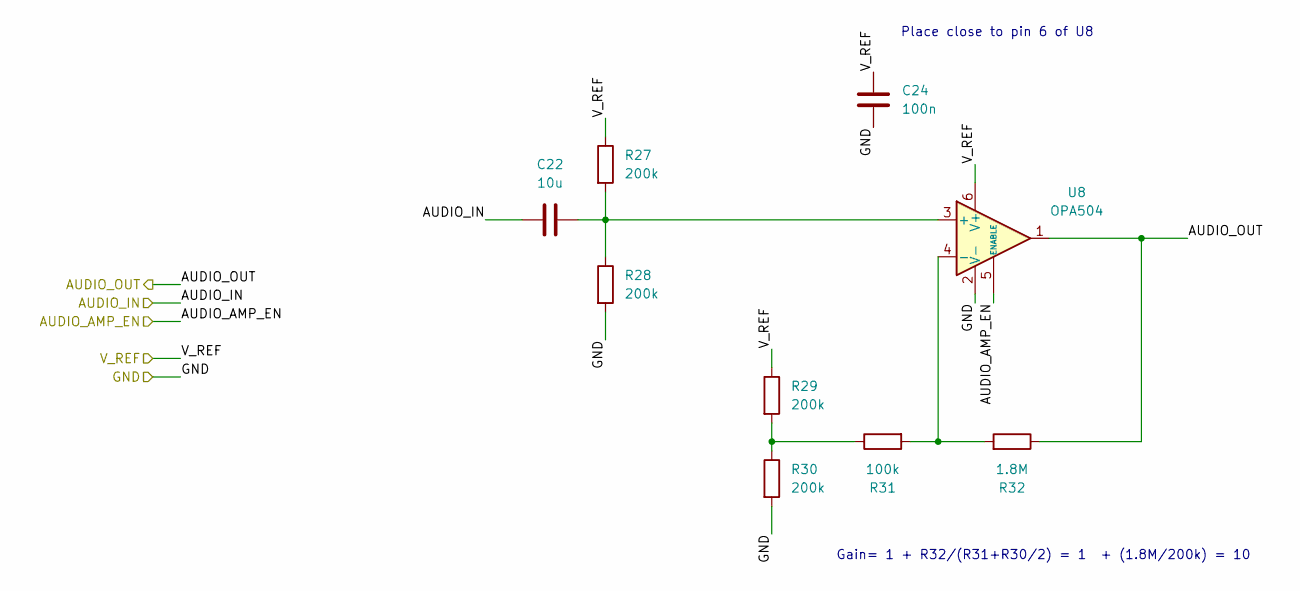
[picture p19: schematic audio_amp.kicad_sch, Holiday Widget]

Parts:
C22: 10u; C_0603_1608Metric_Pad1.08x0.95mm_HandSolder; MPN CL10A106MQ8NNNC
C24: 100n; C_0402_1005Metric; MPN CL05A104KA5NNNC
R27, R28, R29, R30: 200k; R_0402_1005Metric; MPN RC0402FR-07200KL
R31: 100k; R_0402_1005Metric; MPN RC0402FR-07100KL
R32: 1.8M; R_0402_1005Metric; MPN RC0402JR-071M8L
U8: OPA504; SOT-23-6

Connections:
/Audio Amp/AUDIO_AMP_EN: U8.5 (ENABLE); also elsewhere on the board
/Audio Amp/AUDIO_IN: C22.1; also elsewhere on the board
/Audio Amp/AUDIO_OUT: R32.1, U8.1; also elsewhere on the board
/GND: C24.1, R28.2, R30.2, U8.2 (V-); also elsewhere on the board
/VDD: C24.2, R27.1, R29.1, U8.6 (V+); also elsewhere on the board
unnamed: R29.2, R30.1, R31.1
unnamed: C22.2, R27.2, R28.1, U8.3 (+)
unnamed: R31.2, R32.2, U8.4 (-)

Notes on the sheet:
Gain= 1 + R32/(R31+R30/2) = 1 + (1.8M/200k) = 10
Place close to pin 6 of U8

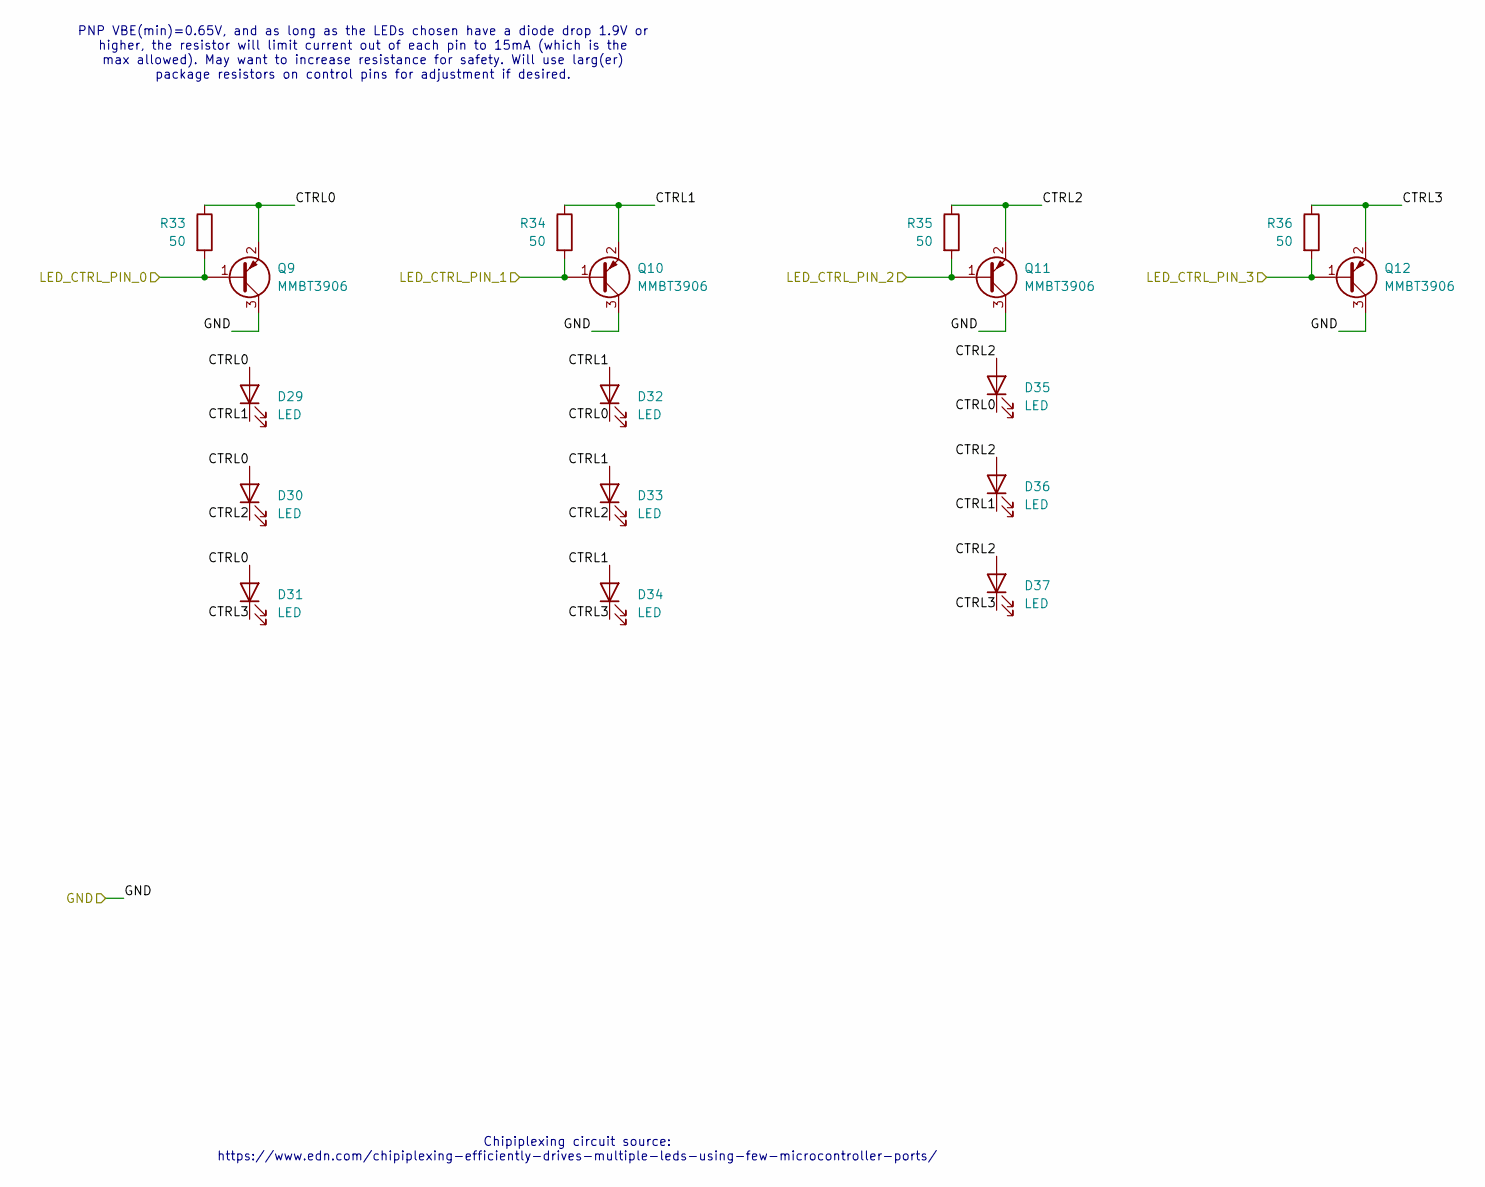
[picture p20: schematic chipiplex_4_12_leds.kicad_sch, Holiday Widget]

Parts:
D29, D30, D31, D32, D33, D34, D35, D36, D37: LED; LED_0805_2012Metric_Pad1.15x1.40mm_HandSolder; MPN LTST-C171GKT
Q9, Q10, Q11, Q12: MMBT3906; SOT-23; MPN MMBT3906
R33, R34, R35, R36: 50; R_0402_1005Metric; MPN RC0402JR-0750RL

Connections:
/GND: Q9.3 (C), Q10.3 (C), Q11.3 (C), Q12.3 (C); also elsewhere on the board
/Input and Output/LED Output2/CTRL0: D29.2 (A), D30.2 (A), D31.2 (A), D32.1 (K), D35.1 (K), Q9.2 (E), R33.1
/Input and Output/LED Output2/CTRL1: D29.1 (K), D32.2 (A), D33.2 (A), D34.2 (A), D36.1 (K), Q10.2 (E), R34.1
/Input and Output/LED Output2/CTRL2: D30.1 (K), D33.1 (K), D35.2 (A), D36.2 (A), D37.2 (A), Q11.2 (E), R35.1
/Input and Output/LED Output2/CTRL3: D31.1 (K), D34.1 (K), D37.1 (K), Q12.2 (E), R36.1
/mcu/LED10: Q9.1 (B), R33.2; also elsewhere on the board
/mcu/LED11: Q10.1 (B), R34.2; also elsewhere on the board
/mcu/LED12: Q11.1 (B), R35.2; also elsewhere on the board
/mcu/LED13: Q12.1 (B), R36.2; also elsewhere on the board

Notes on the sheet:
Chipiplexing circuit source: https://www.edn.com/chipiplexing-efficiently-drives-multiple-leds-using-few-microcontroller-ports/
PNP VBE(min)=0.65V, and as long as the LEDs chosen have a diode drop 1.9V or higher, the resistor will limit current out of each pin to 15mA (which is the max allowed). May want to increase resistance for safety. Will use larg(er) package resistors on control pins for adjustment if desired.

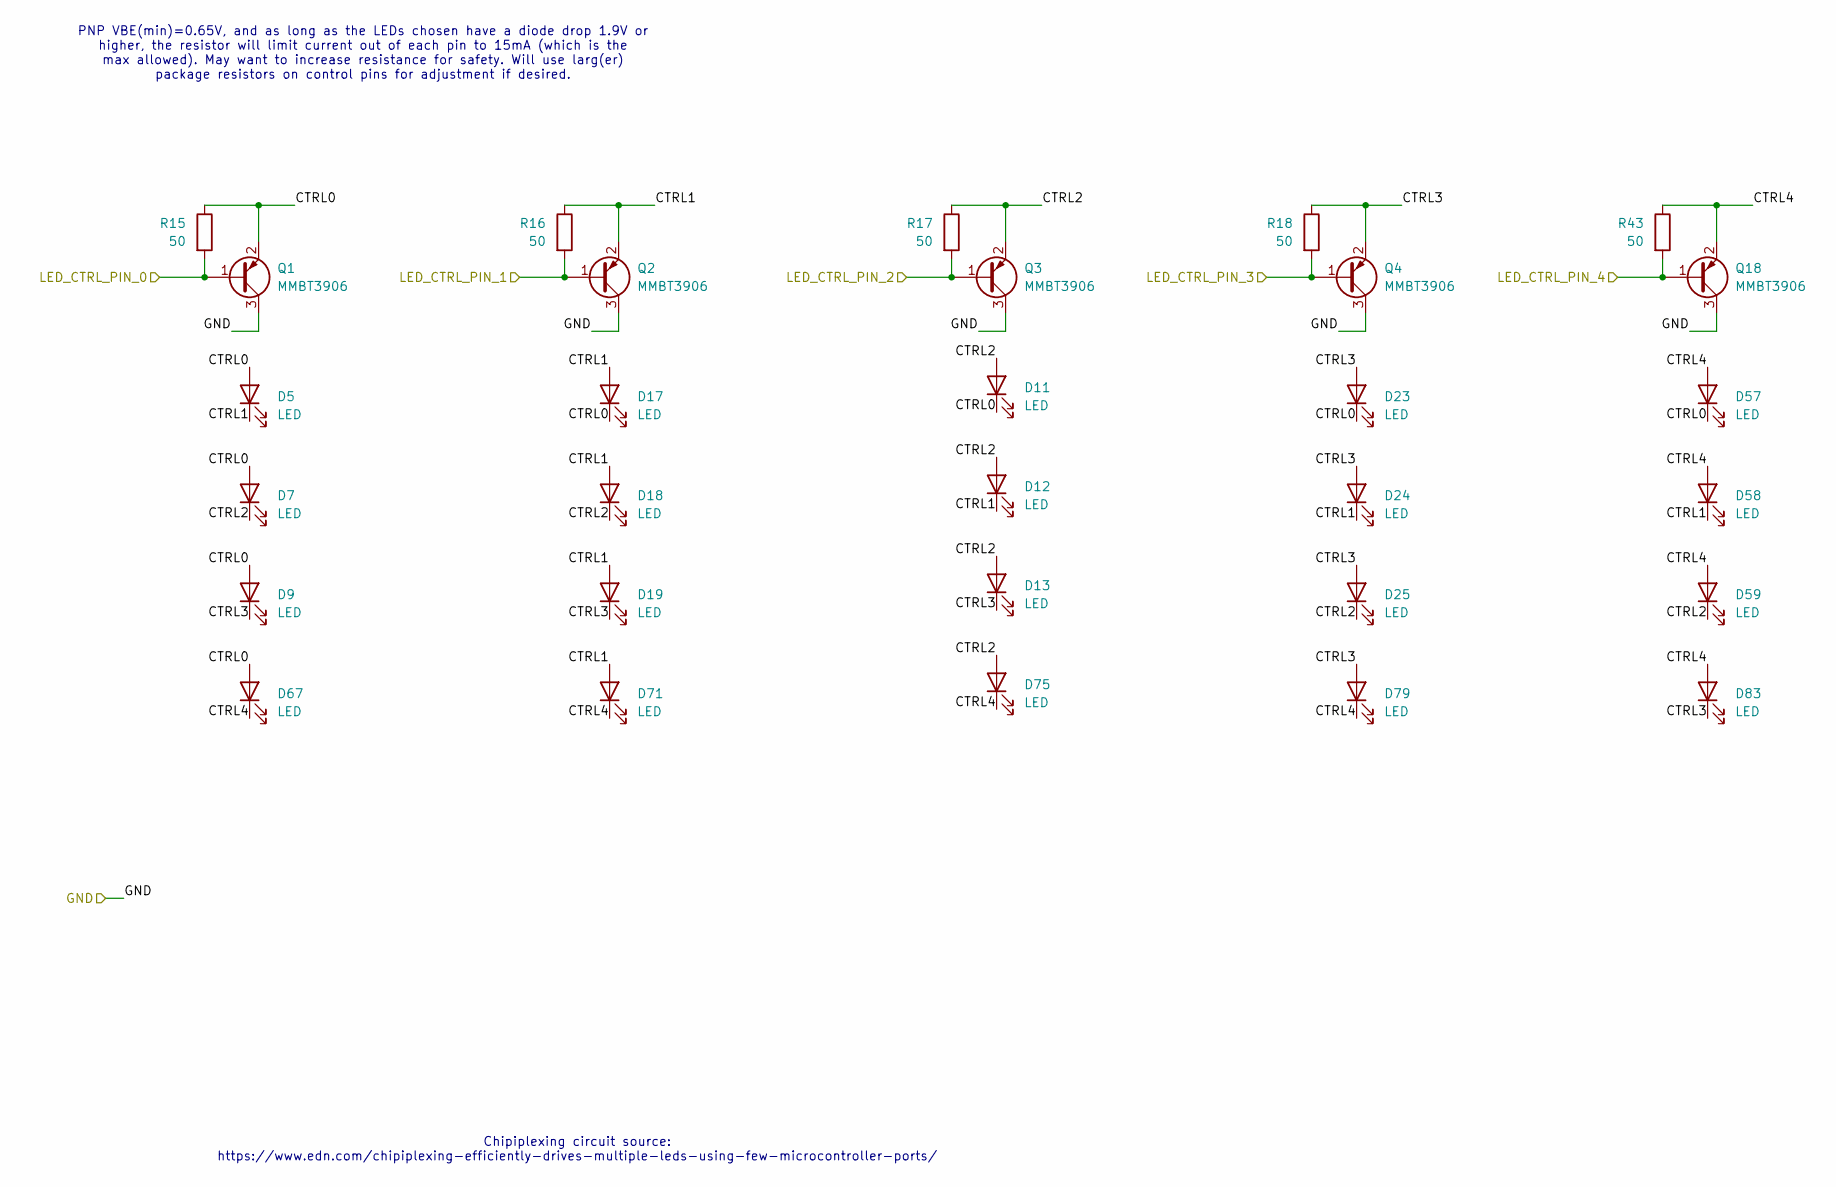
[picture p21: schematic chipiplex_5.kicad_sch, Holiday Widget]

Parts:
D5, D7, D9, D11, D12, D13, D17, D18, D19, D23, D24, D25, D57, D58, D59, D67, D71, D75, D79, D83: LED; LED_0805_2012Metric_Pad1.15x1.40mm_HandSolder; MPN LTST-C171GKT
Q1, Q2, Q3, Q4, Q18: MMBT3906; SOT-23; MPN MMBT3906
R15, R16, R17, R18, R43: 50; R_0402_1005Metric; MPN RC0402JR-0750RL

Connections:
/GND: Q1.3 (C), Q2.3 (C), Q3.3 (C), Q4.3 (C), Q18.3 (C); also elsewhere on the board
/Input and Output/LED Output/CTRL0: D5.2 (A), D7.2 (A), D9.2 (A), D11.1 (K), D17.1 (K), D23.1 (K), D57.1 (K), D67.2 (A), Q1.2 (E), R15.1
/Input and Output/LED Output/CTRL1: D5.1 (K), D12.1 (K), D17.2 (A), D18.2 (A), D19.2 (A), D24.1 (K), D58.1 (K), D71.2 (A), Q2.2 (E), R16.1
/Input and Output/LED Output/CTRL2: D7.1 (K), D11.2 (A), D12.2 (A), D13.2 (A), D18.1 (K), D25.1 (K), D59.1 (K), D75.2 (A), Q3.2 (E), R17.1
/Input and Output/LED Output/CTRL3: D9.1 (K), D13.1 (K), D19.1 (K), D23.2 (A), D24.2 (A), D25.2 (A), D79.2 (A), D83.1 (K), Q4.2 (E), R18.1
/Input and Output/LED Output/CTRL4: D57.2 (A), D58.2 (A), D59.2 (A), D67.1 (K), D71.1 (K), D75.1 (K), D79.1 (K), D83.2 (A), Q18.2 (E), R43.1
/mcu/LED0: Q1.1 (B), R15.2; also elsewhere on the board
/mcu/LED1: Q2.1 (B), R16.2; also elsewhere on the board
/mcu/LED2: Q3.1 (B), R17.2; also elsewhere on the board
/mcu/LED3: Q4.1 (B), R18.2; also elsewhere on the board
/mcu/LED4: Q18.1 (B), R43.2; also elsewhere on the board

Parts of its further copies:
D6, D8, D10, D14, D15, D16, D20, D21, D22, D26, D27, D28, D60, D61, D62, D68, D72, D76, D80, D84: LED; LED_0805_2012Metric_Pad1.15x1.40mm_HandSolder; MPN LTST-C171GKT
Q5, Q6, Q7, Q8, Q19: MMBT3906; SOT-23; MPN MMBT3906
R19, R20, R21, R22, R44: 50; R_0402_1005Metric; MPN RC0402JR-0750RL

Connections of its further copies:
/GND: Q5.3 (C), Q6.3 (C), Q7.3 (C), Q8.3 (C), Q19.3 (C); also elsewhere on the board
/Input and Output/LED Output1/CTRL0: D6.2 (A), D8.2 (A), D10.2 (A), D14.1 (K), D20.1 (K), D26.1 (K), D60.1 (K), D68.2 (A), Q5.2 (E), R19.1
/Input and Output/LED Output1/CTRL1: D6.1 (K), D15.1 (K), D20.2 (A), D21.2 (A), D22.2 (A), D27.1 (K), D61.1 (K), D72.2 (A), Q6.2 (E), R20.1
/Input and Output/LED Output1/CTRL2: D8.1 (K), D14.2 (A), D15.2 (A), D16.2 (A), D21.1 (K), D28.1 (K), D62.1 (K), D76.2 (A), Q7.2 (E), R21.1
/Input and Output/LED Output1/CTRL3: D10.1 (K), D16.1 (K), D22.1 (K), D26.2 (A), D27.2 (A), D28.2 (A), D80.2 (A), D84.1 (K), Q8.2 (E), R22.1
/Input and Output/LED Output1/CTRL4: D60.2 (A), D61.2 (A), D62.2 (A), D68.1 (K), D72.1 (K), D76.1 (K), D80.1 (K), D84.2 (A), Q19.2 (E), R44.1
/mcu/LED5: Q5.1 (B), R19.2; also elsewhere on the board
/mcu/LED6: Q6.1 (B), R20.2; also elsewhere on the board
/mcu/LED7: Q7.1 (B), R21.2; also elsewhere on the board
/mcu/LED8: Q8.1 (B), R22.2; also elsewhere on the board
/mcu/LED9: Q19.1 (B), R44.2; also elsewhere on the board

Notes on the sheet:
Chipiplexing circuit source: https://www.edn.com/chipiplexing-efficiently-drives-multiple-leds-using-few-microcontroller-ports/
PNP VBE(min)=0.65V, and as long as the LEDs chosen have a diode drop 1.9V or higher, the resistor will limit current out of each pin to 15mA (which is the max allowed). May want to increase resistance for safety. Will use larg(er) package resistors on control pins for adjustment if desired.

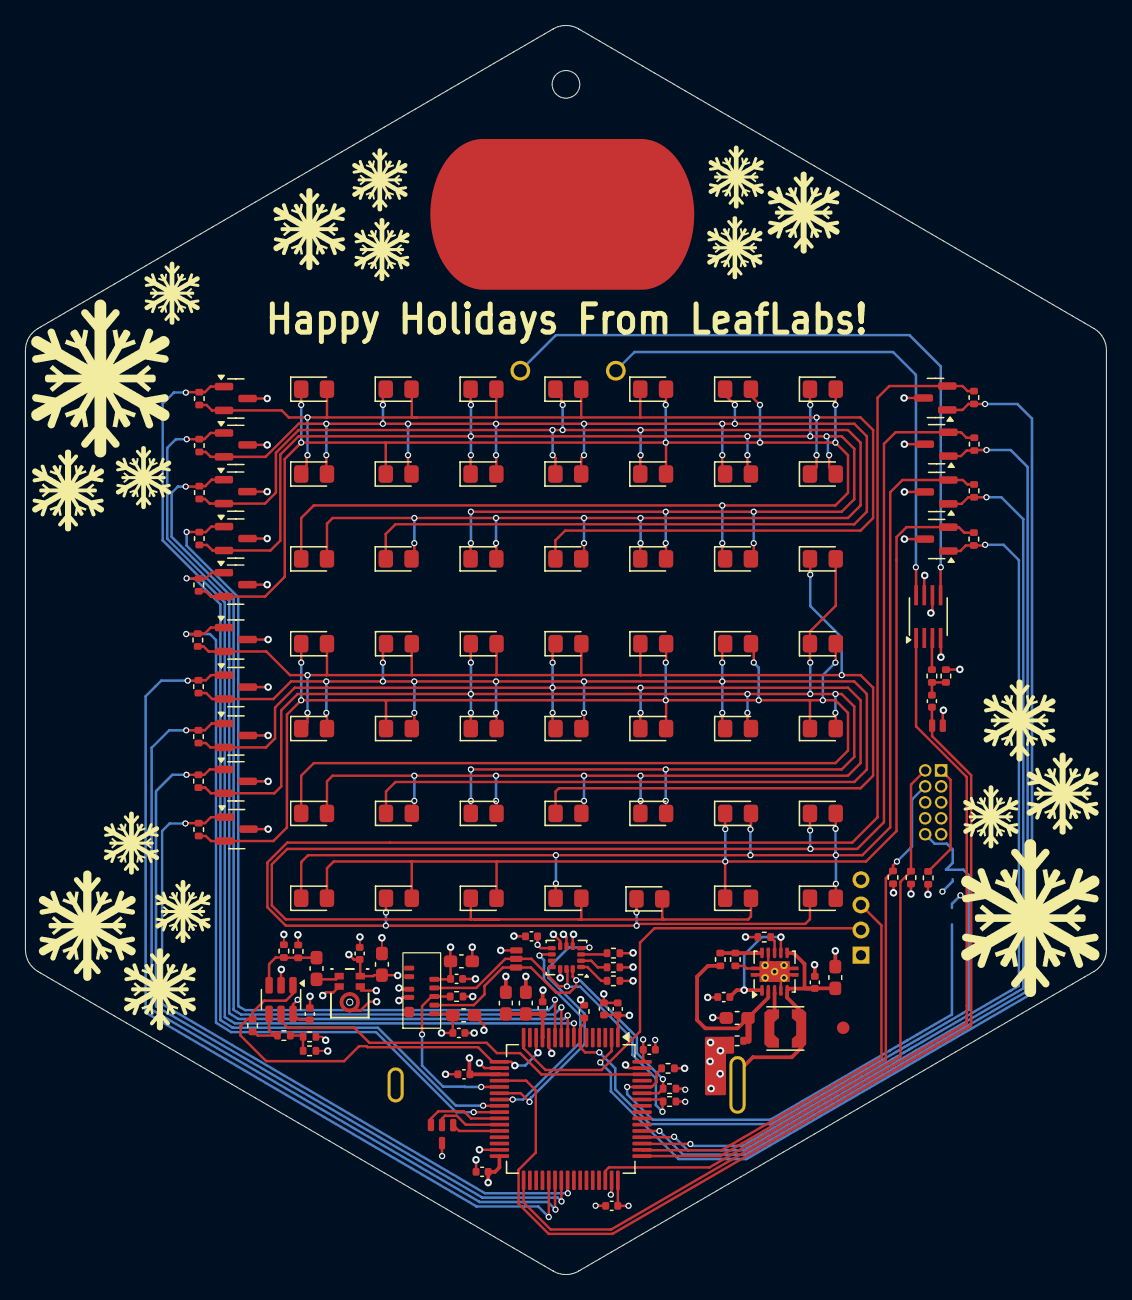
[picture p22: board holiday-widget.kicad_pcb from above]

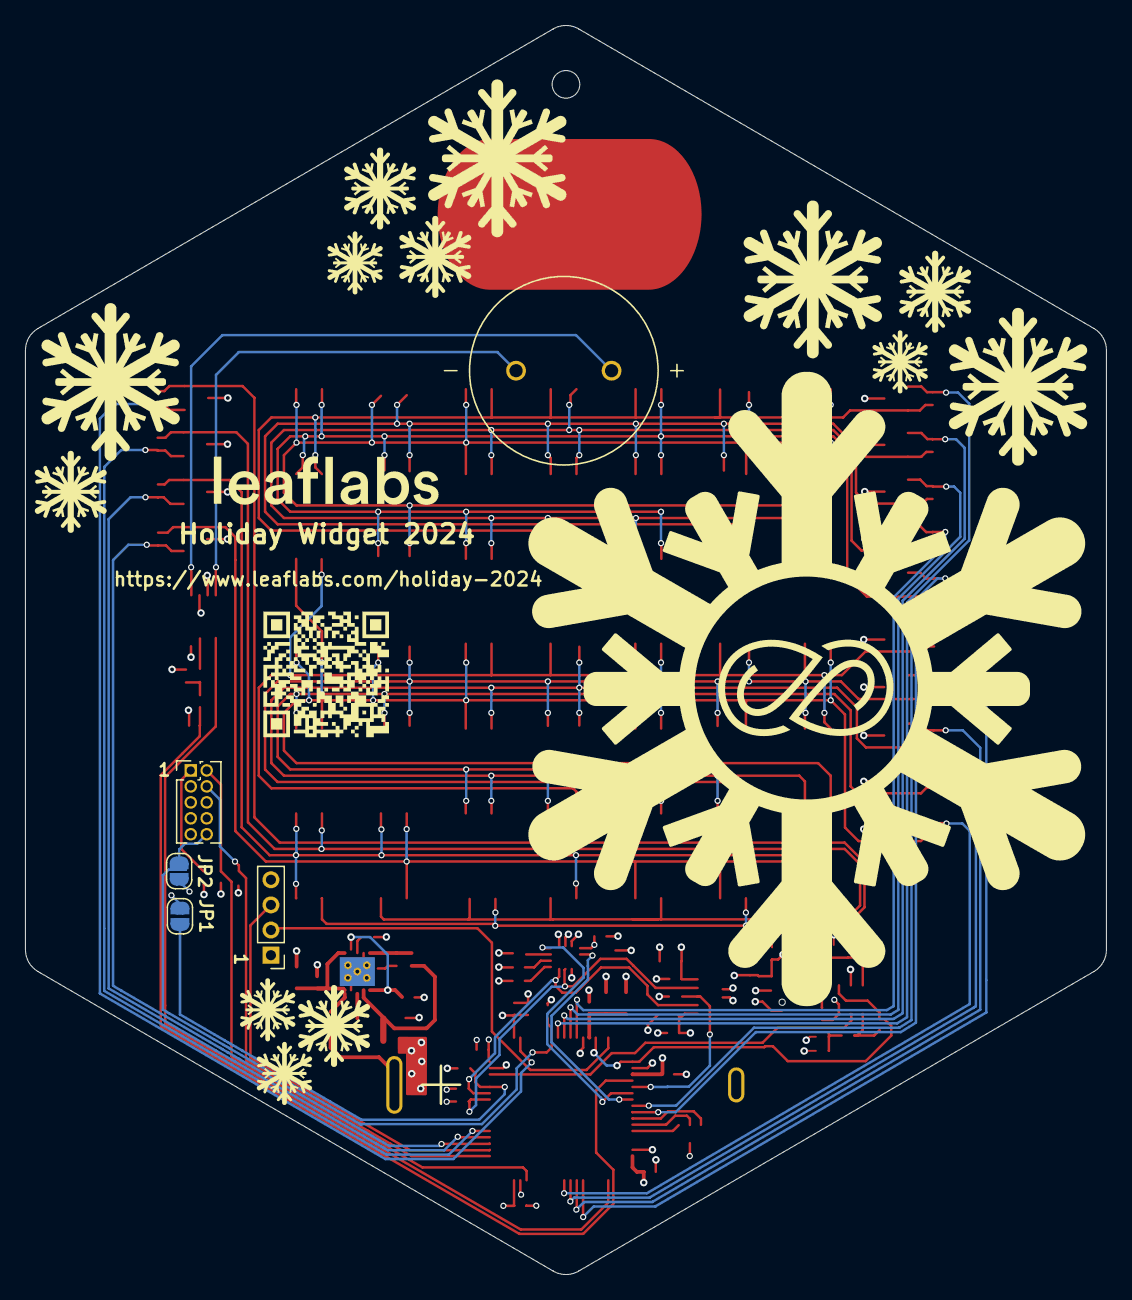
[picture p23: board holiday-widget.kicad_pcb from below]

Board: 4 copper layers, 86.0 x 99.4 mm, 146 parts (6 on the bottom side), 67 nets.

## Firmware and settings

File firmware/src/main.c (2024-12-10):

#include "acceleration.h"
#include "ambient_light.h"
#include "game_engine.h"
#include "job_queue.h"
#include "led_matrix.h"
#include "music_player.h"
#include "widget_controller.h"
#include "widget_system.h"

int main(void) {
    widget_system_init();

    job_add(&system_communication_setup, JOB_INIT);

    job_add(&widget_controller_setup, JOB_INIT);

    job_add(&acceleration_setup, JOB_INIT);
    job_add(&ambient_light_setup, JOB_INIT);
    job_add(&led_matrix_setup, JOB_INIT);
    job_add(&music_player_setup, JOB_INIT);
    job_add(&game_engine_setup, JOB_INIT);

    job_add(&uart_logger_run, JOB_RUN_RUN);
    job_add(&system_communication_run, JOB_RUN_RUN);

    job_add(&acceleration_run, JOB_RUN_RUN);
    job_add(&ambient_light_run, JOB_RUN_RUN);

    job_add(&led_matrix_loader_run, JOB_RUN_RUN);
    job_add(&led_matrix_renderer_run, JOB_RUN_RUN);
    job_add(&led_matrix_assembler_run, JOB_RUN_RUN);

    job_add(&music_player_run, JOB_RUN_RUN);
    job_add(&game_engine_run, JOB_RUN_RUN);
    job_add(&widget_controller_run, JOB_RUN_RUN);

    while (1) {
        job_state_machine_run();
    }
}

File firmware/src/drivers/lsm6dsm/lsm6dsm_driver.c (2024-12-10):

#include "lsm6dsm_driver.h"

#include <errno.h>

#include "arm_math.h"
#include "futures.h"
#include "generic_gpio.h"
#include "i2c_driver.h"
#include "logging.h"
#include "lsm6dsm_registers.h"
#include "system_communication.h"
#include "utils.h"

#define LSM6DSM_MAX_I2C_SIZE 6U

/* Converts the given value in degrees to radians */
#define DEGREES_TO_RADIANS(__degrees__) ((__degrees__ * PI) / 180.0f)

/*
    Converts the given threshold in radians to the nearest
    equivalent valid LSM6DSM A_WRIST_TILT_THS register value.
    If an invalid threshold is provided, evaluates to the default
    register value of 0x20 (π/4 radians).
*/
#define LSM6DSM_WT_THRESHOLD_FROM_RADIANS(__radians__) \
    (__radians__ >= 0U && __radians__ < (PI / 2.0f)    \
         ? (uint8_t)(arm_sin_f32(__radians__) * 64.0f) \
         : 0x20)

/*
    Converts the given threshold in degrees to the nearest
    equivalent valid LSM6DSM A_WRIST_TILT_THS register value.
    If an invalid threshold is provided, evaluates to the default
    register value of 0x20 (30 degrees).
*/
#define LSM6DSM_WT_THRESHOLD_FROM_DEGREES(__degrees__) \
    (LSM6DSM_WT_THRESHOLD_FROM_RADIANS(DEGREES_TO_RADIANS(__degrees__)))

/*
    Converts the given latency in milliseconds to the nearest
    equivalent valid LSM6DSM A_WRIST_TILT_LAT register value.
    To avoid truncation error from integer division, choose
    latency values that are integer multiples of 40 milliseconds.
    If an invalid latency is provided, evaluates to the default
    register value of 0x0F (600 milliseconds).
*/
#define LSM6DSM_WT_LATENCY_FROM_MS(__ms__)                       \
    (__ms__ >= 0U && __ms__ <= 10200U ? (uint8_t)(__ms__ / 40.0) \
                                      : (uint8_t)0x0F)

/*
    Converts the given threshold in milli-g's to the nearest
    equivalent valid WK_THS field value of LSM6DSM WAKE_UP_THS register.
    If an invalid threshold is provided, evaluates to arbitrary default
    value of 0x01 (FS_XL/64 g).
*/
/* clang-format off */
#define LSM6DSM_WK_THRESHOLD_FROM_MG(__mg__, __fs_xl__)                     \
    (__fs_xl__ >= LSM6DSM_2g                                                \
    && __fs_xl__ <= LSM6DSM_8g                                              \
    && __mg__ >= 0.0f                                                       \
    && __mg__ <= lsm6dsm_fs_xl_value_mg[__fs_xl__]                          \
    ? (uint8_t)((__mg__ * 64.0) / lsm6dsm_fs_xl_value_mg[__fs_xl__])        \
    : (uint8_t)0x01)
/* clang-format on */

/*
    Converts the given sleep duration in ms to the nearest
    equivalent valid SLEEP_DUR field value of LSM6DSM WAKE_UP_DUR register.
    If an invalid threshold is provided, evaluates to arbitrary default
    value of 0x01 (512/ODR_XL g).
*/
/* clang-format off */
#define LSM6DSM_WK_DURATION_FROM_MS(__ms__, __odr_xl__)                 \
    (__odr_xl__ >= LSM6DSM_XL_ODR_OFF                                   \
    && __odr_xl__ <= LSM6DSM_XL_ODR_1Hz6                                \
    && __ms__ >= 0.0f                                                   \
    && __ms__ <= 15.0f * 512.0f * lsm6dsm_odr_xl_value_ms[__odr_xl__]   \
    ? (uint8_t)(__ms__/(lsm6dsm_odr_xl_value_ms[__odr_xl__]*512.0f))    \
    : (uint8_t)0x01)
/* clang-format on */

/*
    Converts the given threshold in milli-g's to the nearest
    equivalent valid TAP_THS field value of LSM6DSM TAP_THS_6D register.
    If an invalid threshold is provided, evaluates to arbitrary default
    value of 0x01 (FS_XL/32 g).
*/
/* clang-format off */
#define LSM6DSM_TAP_THRESHOLD_FROM_MG(__mg__, __fs_xl__)                    \
    (__fs_xl__ >= LSM6DSM_2g                                                \
    && __fs_xl__ <= LSM6DSM_8g                                              \
    && __mg__ >= lsm6dsm_fs_xl_value_mg[__fs_xl__]/32.0f                    \
    && __mg__ <= lsm6dsm_fs_xl_value_mg[__fs_xl__]                          \
    ? (uint8_t)((__mg__ * 32.0f) / lsm6dsm_fs_xl_value_mg[__fs_xl__])       \
    : (uint8_t)0x01)
/* clang-format on */

/*
    Converts the given duration in milliseconds to the nearest
    equivalent valid DUR field value of LSM6DSM INT_DUR2 register.
    If an invalid duration is provided, evaluates to default
    value of 0x00 (32/ODR_XL g; 16/ODR_XL g if 0x00).
*/
/* clang-format off */
#define LSM6DSM_TAP_DURATION_FROM_MS(__ms__, __odr_xl__)                   \
    (__odr_xl__ >= LSM6DSM_XL_ODR_OFF                                      \
    && __odr_xl__ <= LSM6DSM_XL_ODR_1Hz6                                   \
    && __ms__ >= 32.0f * lsm6dsm_odr_xl_value_ms[__odr_xl__]               \
    && __ms__ <= (0b1111 * 32.0f * lsm6dsm_odr_xl_value_ms[__odr_xl__])    \
    ? (uint8_t)(__ms__/(lsm6dsm_odr_xl_value_ms[__odr_xl__]*32.0f))        \
    : (uint8_t)0x00)
/* clang-format on */

/*
    Converts the given quiet time in milliseconds to the nearest
    equivalent valid QUIET field value of LSM6DSM INT_DUR2 register.
    If an invalid quiet time is provided, evaluates to default
    value of 0x00 (4/ODR_XL g; 2/ODR_XL g if 0x00).
*/
/* clang-format off */
#define LSM6DSM_TAP_QUIET_FROM_MS(__ms__, __odr_xl__)                  \
    (__odr_xl__ >= LSM6DSM_XL_ODR_OFF                                  \
    && __odr_xl__ <= LSM6DSM_XL_ODR_1Hz6                               \
    && __ms__ >= 4.0f * lsm6dsm_odr_xl_value_ms[__odr_xl__]            \
    && __ms__ <= (0b11 * 4.0f * lsm6dsm_odr_xl_value_ms[__odr_xl__])   \
    ? (uint8_t)(__ms__/(lsm6dsm_odr_xl_value_ms[__odr_xl__]*4.0f))     \
    : (uint8_t)0x00)
/* clang-format on */

/*
    Converts the given shock time in milliseconds to the nearest
    equivalent valid SHOCK field value of LSM6DSM INT_DUR2 register.
    If an invalid shock time is provided, evaluates to default
    value of 0x00 (8/ODR_XL g; 4/ODR_XL g if 0x00).
*/
/* clang-format off */
#define LSM6DSM_TAP_SHOCK_FROM_MS(__ms__, __odr_xl__)                  \
    (__odr_xl__ >= LSM6DSM_XL_ODR_OFF                                  \
    && __odr_xl__ <= LSM6DSM_XL_ODR_1Hz6                               \
    && __ms__ >= 8.0f * lsm6dsm_odr_xl_value_ms[__odr_xl__]            \
    && __ms__ <= (0b11 * 8.0f * lsm6dsm_odr_xl_value_ms[__odr_xl__])   \
    ? (uint8_t)(__ms__/(lsm6dsm_odr_xl_value_ms[__odr_xl__]*8.0f))     \
    : (uint8_t)0x00)
/* clang-format on */
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

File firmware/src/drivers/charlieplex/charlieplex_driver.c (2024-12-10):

#include "charlieplex_driver.h"

#include <stdbool.h>

#include "logging.h"
#include "stm32l072xx.h"
#include "utils.h"

static const uint8_t default_leds[NUM_LEDS] = {0};

static volatile uint32_t t1, t2, duration;

struct charlieplex_driver_config {
    uint32_t prescaler;
    uint32_t refresh_rate;
    TIM_TypeDef *tim;
} __attribute__((aligned(4)));

struct charlieplex_driver_context {
    TIM_HandleTypeDef htim;
    volatile uint8_t *leds[2];
    volatile uint32_t moder_buffer[2][__NUM_LED_FRAMES];
    volatile uint8_t current_buffer;
    volatile bool update_requested;
    volatile enum led_frame current_frame;
} __attribute__((aligned(4)));

struct charlieplex_driver {
    const struct charlieplex_driver_config *config;
    struct charlieplex_driver_context *context;
} __attribute__((aligned(4)));

static const struct charlieplex_driver_config config = {
    .refresh_rate = 180U,
    .tim = TIM7,
};

static struct charlieplex_driver_context context = {
    .htim = {0},
    .leds =
        {
            default_leds,
            default_leds,
        },
    .current_buffer = 0,
    .update_requested = false,
    .current_frame = LED_FRAME_1,
};

static const struct charlieplex_driver charlieplex_driver_inst = {
    .config = &config,
    .context = &context,
};

const struct charlieplex_driver *const charlieplex_driver =
    &charlieplex_driver_inst;

/*
    List of all LEDs possible to turn on.

    The DEFAULT_LED takes up the 0th index to allow for
    writing 0 to have no effect. This is used to avoid checking
    if an led is on or not.

    Setting an LED requires setting the led's value in an array to
    itself. Ex: leds[D9] = D9;
*/

/*
    List every control line (GPIO pin)
    so we can index into an array with the value.
*/
enum controls {
    CTRL0 = 0x0,
    CTRL1 = 0x1,
    CTRL2 = 0x2,
    CTRL3 = 0x3,
    CTRL4 = 0x4,
    CTRL5 = 0x5,
    CTRL6 = 0x6,
    CTRL7 = 0x7,
    CTRL8 = 0x8,
    CTRL9 = 0x9,
    CTRL10 = 0xA,
    CTRL11 = 0xB,
    CTRL12 = 0xC,
    CTRL13 = 0xD,
    NO_CTRL = 0xE,
};

enum leds {
    DUMMY_LED,
    D67,
    D5,
    D9,
    D7,
    D57,
    D58,
    D83,

    D17,
    D71,
    D19,
    D18,
    D59,
    D24,
    D23,

    D75,
    D12,
    D13,
    D11,
    D25,
    D79,
    D26,

    D68,
    D6,
    D10,
    D8,
    D60,
    D61,
    D84,

    D20,
    D72,
    D22,
    D21,
    D62,
    D27,
    D80,

    D76,
    D15,
    D16,
    D14,
    D28,
    D32,
    D33,

    D29,
    D31,
    D30,
    D36,
    D37,
    D35,
    D34,
};

// Count of LEDs in the selected frame
static const uint8_t led_count[__NUM_LED_FRAMES] = {
    [LED_FRAME_1] = 11U, [LED_FRAME_2] = 11U, [LED_FRAME_3] = 11U,
    [LED_FRAME_4] = 8U,  [LED_FRAME_5] = 8U,
};

// LED and Control mapping arrays for ENABLE and DISABLE modes
static const enum controls mode[2][NUM_LEDS] = {
    [DISABLE] = {[0 ... NUM_LEDS - 1] =
                     NO_CTRL},  // Set all entries to NO_CTRL for DISABLE mode
    [ENABLE] = {
        [D67] = CTRL4,  [D5] = CTRL1,   [D9] = CTRL3,   [D7] = CTRL2,
        [D57] = CTRL0,  [D58] = CTRL1,  [D59] = CTRL2,  [D83] = CTRL3,
        [D17] = CTRL0,  [D71] = CTRL4,  [D19] = CTRL3,  [D18] = CTRL2,
        [D24] = CTRL1,  [D23] = CTRL0,  [D75] = CTRL4,  [D12] = CTRL1,
        [D13] = CTRL3,  [D11] = CTRL0,  [D25] = CTRL2,  [D79] = CTRL4,
        [D26] = CTRL5,  [D68] = CTRL9,  [D6] = CTRL6,   [D10] = CTRL8,
        [D8] = CTRL7,   [D60] = CTRL5,  [D61] = CTRL6,  [D84] = CTRL8,
        [D20] = CTRL5,  [D72] = CTRL9,  [D22] = CTRL8,  [D21] = CTRL7,
        [D62] = CTRL7,  [D27] = CTRL6,  [D80] = CTRL9,  [D76] = CTRL9,
        [D15] = CTRL6,  [D16] = CTRL8,  [D14] = CTRL5,  [D28] = CTRL7,
        [D32] = CTRL10, [D33] = CTRL12, [D29] = CTRL11, [D31] = CTRL13,
        [D30] = CTRL12, [D36] = CTRL11, [D37] = CTRL13, [D35] = CTRL10,
        [D34] = CTRL13,
    }};

// Frame LED mapping
static const enum leds frame_led_map[__NUM_LED_FRAMES][11] = {
    [LED_FRAME_1] = {D5, D7, D9, D67, D6, D8, D10, D68, D29, D30, D31},
    [LED_FRAME_2] = {D11, D12, D13, D75, D14, D15, D16, D76, D35, D36, D37},
    [LED_FRAME_3] = {D17, D18, D19, D71, D20, D21, D22, D72, D32, D33, D34},
    [LED_FRAME_4] = {D23, D24, D25, D79, D26, D27, D28, D80},
    [LED_FRAME_5] = {D57, D58, D59, D83, D60, D61, D62, D84},
};

// Control pin and mode mappings
static const uint32_t ctrl_pin_map[2][15] = {
    [DISABLE] = {[CTRL0... CTRL13] = 0U, [NO_CTRL] = 0U},
    [ENABLE] = {[CTRL0] = GPIO_PIN_0,
                [CTRL1] = GPIO_PIN_1,
                [CTRL2] = GPIO_PIN_2,
                [CTRL3] = GPIO_PIN_3,
                [CTRL4] = GPIO_PIN_4,
                [CTRL5] = GPIO_PIN_5,
                [CTRL6] = GPIO_PIN_6,
                [CTRL7] = GPIO_PIN_7,
                [CTRL8] = GPIO_PIN_8,
                [CTRL9] = GPIO_PIN_9,
                [CTRL10] = GPIO_PIN_10,
                [CTRL11] = GPIO_PIN_11,
                [CTRL12] = GPIO_PIN_12,
                [CTRL13] = GPIO_PIN_13,
                [NO_CTRL] = 0U}};

// Control mode mapping for MODER registers
static const uint32_t ctrl_output_mode_map[] = {
    [CTRL0] = 0x1,        [CTRL1] = 0x4,        [CTRL2] = 0x10,
    [CTRL3] = 0x40,       [CTRL4] = 0x100,      [CTRL5] = 0x400,
    [CTRL6] = 0x1000,     [CTRL7] = 0x4000,     [CTRL8] = 0x10000,
    [CTRL9] = 0x40000,    [CTRL10] = 0x100000,  [CTRL11] = 0x400000,
    [CTRL12] = 0x1000000, [CTRL13] = 0x4000000, [NO_CTRL] = 0x0};

// Frame control MODER and ODR values
static const uint32_t led_frame_ctrl_moder[] = {
    [LED_FRAME_1] = (ctrl_output_mode_map[CTRL0] | ctrl_output_mode_map[CTRL5] |
                     ctrl_output_mode_map[CTRL10]),
    [LED_FRAME_2] = (ctrl_output_mode_map[CTRL2] | ctrl_output_mode_map[CTRL7] |
                     ctrl_output_mode_map[CTRL12]),
    [LED_FRAME_3] = (ctrl_output_mode_map[CTRL1] | ctrl_output_mode_map[CTRL6] |
                     ctrl_output_mode_map[CTRL11]),
    [LED_FRAME_4] = (ctrl_output_mode_map[CTRL3] | ctrl_output_mode_map[CTRL8] |
                     ctrl_output_mode_map[CTRL13]),
    [LED_FRAME_5] = (ctrl_output_mode_map[CTRL4] | ctrl_output_mode_map[CTRL9]),
};

static const uint32_t led_frame_ctrl_odr[] = {
    [LED_FRAME_1] = (ctrl_pin_map[ENABLE][CTRL0] | ctrl_pin_map[ENABLE][CTRL5] |
                     ctrl_pin_map[ENABLE][CTRL10]),
    [LED_FRAME_2] = (ctrl_pin_map[ENABLE][CTRL2] | ctrl_pin_map[ENABLE][CTRL7] |
                     ctrl_pin_map[ENABLE][CTRL12]),
    [LED_FRAME_3] = (ctrl_pin_map[ENABLE][CTRL1] | ctrl_pin_map[ENABLE][CTRL6] |
                     ctrl_pin_map[ENABLE][CTRL11]),
    [LED_FRAME_4] = (ctrl_pin_map[ENABLE][CTRL3] | ctrl_pin_map[ENABLE][CTRL8] |
                     ctrl_pin_map[ENABLE][CTRL13]),
    [LED_FRAME_5] = (ctrl_pin_map[ENABLE][CTRL4] | ctrl_pin_map[ENABLE][CTRL9]),
};
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

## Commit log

2024-05-18 [Hardware] v1.0 PCB
    Initial PCB design for holiday widget sent to JLCPCB.
    [holiday-widget-B_Cu.gbl, holiday-widget-B_Mask.gbs, holiday-widget-B_Paste.gbp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]
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2024-05-28 Basic startup code for NUCLEO-L053R8 board.
    Added git submodule for STM32CubeL0 repo.
    Set up HAL library and added CMSIS functionality.
    Set up linker script and Makefile.
    Source code added to blink led when user button is pressed.
    Removed dependency on C library and added builtin functions required for compilation
2024-05-31 Added message logging using the uart. Added submodule for a smaller version of printf and friends. Uart code lives in separate file so only uart_logger_init() needs to be called before using uart_log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
2024-06-04 Refactored code to use an interrupt file. Fixed issue where a HAL template file was overriding the default HAL clock implementation and using a different timer than the SysTick_Handler.
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2024-06-07 Set up a basic I2C driver for the tmp102 sensor. Abstract out code for better readability. Add simple test to read temperature and print to the console every second
2024-06-14 Setup the vcnl4020 driver to measure proximity and ambient light value.
    Supports a user defined handler to process interrupts.
2024-06-17 Revamp the tmp102_driver to be more like the other sensors for configuration and for reading values.
    Add in configuration for how fast the sensor updates values.
2024-06-21 Add Charlieplexing to the holiday widget.
    Changes main's loop to just update LEDs for now.
2024-07-10 Convert i2c transactions to be non blocking. Implement a queue to hold i2c transactions and use futures for signaling when they are finished. Implement a job queue for an easy interface to cycle thro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
2024-07-11 Update case statements to use braces for compliance Remove extra semicolons after functions Fix other warnings
    [acceleration.c, ambient_light.c, charlieplex_driver.c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]
2024-07-19 Add Charlieplexing to the job system. Simulate a 7x7 matrix and display the top 5x5 portion using the leds. Add led dimming. Add interface to setup frames to render. Improve Charlieplexing code to re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
2024-07-24 Add DMA music player to main - Implement low-level PAM8302A (audio amplifier) driver - Implement Music Player Core using timer and DMA to drive DAC output - Implement Music Player "wrapper" to allow 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
2024-07-24 Fix enum naming convention bug - Remove *_t suffix from enum Song_t in music_player_core.c - Remove *_t suffix from enum Song_t in music_player.c
    [music_player_core.c, pam8302a_driver.c, tones.h]
2024-07-24 Simplify I2C related initialization code Add low power mode to each driver
2024-07-26 Setup Docker CI Pipeline. - Add .gitlab-ci.yml with 'check' and 'build' stages - Add code-format Dockerfile for building image for 'check' stage - Add build-firmware Dockerfile for building image for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
2024-07-29 Correct Makefile and linker script. - Add `--print-memory-usage` flag for debug purposes - Change opencd target config file from `target/stm32l0.cfg` to `target/stm32l0_dual_bank.cfg` - Change FLASH 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
2024-08-13 [Hardware] Update MCU pinout.
    * Move UART RX to PA15
    * Route audio input to PA3 in addition to PC0
    [holiday-widget.kicad_pcb, mcu.kicad_sch]
2024-08-13 [Hardware] Add amplifier to microphone output.
    The STM32 part we are using does not include an internal opamp, so we are adding an external opamp to bias and amplify the audio signal.
    * Add opamp opa355
    * calculate resistor network for gain of 10
    [audio_amp.kicad_sch, holiday-widget.kicad_pcb, holiday-widget.kicad_sch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]
2024-08-13 [Hardware] Remove unused breakouts
    * Remove extra GPIO and SPI outputs from MCU
    * remove auxillary connectors for GPIO, SPI, and I2C
    [holiday-widget.kicad_pcb, holiday-widget.kicad_sch, input_output.kicad_sch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]
2024-08-13 [Hardware] Update testpoints
    * Add TPs for I2C since we removed the I2C header
    * Add ground testpoints for GPIO and audio out
    [holiday-widget.kicad_pcb, input_output.kicad_sch, mcu.kicad_sch]
2024-08-13 [Hardware] Remove tmp102
    No longer using the tmp102 temperature sensor, so remove it from the board.
    [holiday-widget.kicad_pcb, sensors.kicad_sch]
2024-08-13 [Hardware] Resize UART header to be 2.54mm pitch.
    Previous revision had incorrectly sized pinout, correct this.
    [holiday-widget.kicad_pcb, holiday-widget.kicad_sch]
2024-08-13 [Hardware] Update LEDs
    Add additional LEDs and arrange in 7x7 matrix. Remove 2x status LEDs. Reroute MCU connetions to be more sensible. Rearrange components.
    [chipiplex_4_12_leds.kicad_sch, chipiplex_5.kicad_sch, holiday-widget.kicad_pcb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]
2024-08-13 [Hardware] Boost converter updates.
    * Tie PS (power save) pin to ground to enable higher efficiencies during low-current operation
    * Add 0ohm resistor at output pin to measure current.
    [holiday-widget.kicad_pcb, power.kicad_sch]
2024-08-13 [Hardware] Replace LISDH Motion Sensor with LSM6DSM
    Change motion sensor to an accelerometer + gyro unit. Route the second interrupt line to the STM32.
    [chipiplex_4_12_leds.kicad_sch, chipiplex_5.kicad_sch, holiday-widget.kicad_pcb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]
2024-08-13 [Hardware] Layout touchups for V2.
    Rearrange components mildly to increase density. Decrease footprint size slightly. Fix silkscreen.
    [holiday-widget.kicad_pcb]
2024-08-13 [Hardware] Add ferrite bead to VDDA. Swap schematic symbol for SWD-specific one. Add some notes to MCU pins.
    [holiday-widget.kicad_pcb, holiday-widget.kicad_sch, mcu.kicad_sch]
2024-08-13 [Hardware] Fix boot button pull-up resistor.
    Had an extra resistor, remove it.
    [holiday-widget.kicad_pcb, mcu.kicad_sch]
2024-08-13 [Hardware] Component changes.
    * Swap op-amp to similar and cheaper OPA504
    * Remove note about tantalum caps (per conversation w Alexa) and plan to replace in BOM with ceramic
    [audio_amp.kicad_sch, holiday-widget.kicad_pcb, mcu.kicad_sch]
2024-08-13 [Hardware] Add V2.0 Manufacturing files.
    [BOM-holiday-widget.csv, holiday-widget.kicad_pcb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]
2024-09-13 Neaten up the layout of the LED array
    [holiday-widget.kicad_pcb]
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2024-09-14 Change many passives to 0402 and assign part numbers
    Incorporate 0402 parts where possible
    Assign Manufacturer Part Numbers to parts where possible
    Update layout for the new passive sizes
    [audio_amp.kicad_sch, chipiplex_4_12_leds.kicad_sch, chipiplex_5.kicad_sch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]
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2024-10-11 Remove external power connector
    [holiday-widget.kicad_pcb, holiday-widget.kicad_sch, power.kicad_sch]
2024-10-11 Replace buttons with jumper pads
    [holiday-widget.kicad_pcb, mcu.kicad_sch]
2024-10-11 Remove status LEDs
    [holiday-widget.kicad_pcb, holiday-widget.kicad_sch, input_output.kicad_sch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]
2024-10-11 Add throughhole speaker
    [AST-01508MR-WT-R--3DModel-STEP-461651.STEP, holiday-widget.kicad_pcb, input_output.kicad_sch]
2024-10-11 Remove some silkscreen text
    [holiday-widget.kicad_pcb]
2024-10-11 New hexagon routing.
    [holiday-widget.kicad_pcb, holiday-widget.kicad_sch]
2024-10-11 Tweak the logo size and placement
    [holiday-widget.kicad_pcb]
2024-10-11 Add a fiducial
    [holiday-widget.kicad_pcb]
2024-10-11 Minor PCB graphics tweaking: Adjust logo letter spacing and update snowflake arrangement.
    [holiday-widget.kicad_pcb]
2024-10-11 Add QR code and website to back silkscreen
    [holiday-widget.kicad_pcb]
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2024-12-10 Correct system clock setup to use MSI and not HSI (was actually using MSI anyways since HSI wasn't properly configured anyways)
    [widget_system.c]
2024-12-10 Remove anti-aliasing functionality - resolution of LED matrix is too low for anti-aliasing to have a positive effect
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2024-12-10 Remove debug task from job queue - initial game state is now handled by widget controller so this is no longer necessary.
    [main.c]
2024-12-10 Add curly braces to case statements
    On gcc toolchain 10.3.1, compilation fails due to "declarations after labels". Fix the
    case statements causing this problem.
    [lsm6dsm_driver.c]
2024-12-10 Remove unneeded casts in initializers to fix compiler complaints
    Some casts in initializers of static/global structures are not being correctly interpreted as constant on gcc 10.3.1. Remove these casts since they are redundant.
    [pam8302a_driver.c]
2024-12-10 Fix interrupted scroll text bug
